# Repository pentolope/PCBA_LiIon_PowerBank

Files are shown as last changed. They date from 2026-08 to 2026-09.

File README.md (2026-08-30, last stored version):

# Single-Cell Li-Ion Power Bank

Single-cell Li-ion power bank board: USB-C input, battery charging and protection, and a regulated 5 V output capable of at least 2 A.

This repository holds the design problem for `PCBA_LiIon_PowerBank`, a single-cell Li-ion power bank board. The brief fixes the functional envelope: a USB-C input, battery charging, battery protection, a regulated 5 V output capable of at least 2 A, fuel/status indication, and a pushbutton-controlled output enable. It also states two process constraints — choose an integrated charger/power-path/boost solution where practical, and respect the layout guidance of the selected power ICs while minimizing high-current loop area — and instructs that stated requirements be treated as authoritative. Everything else is open: the brief names no part, vendor, IC, connector, cell, capacity, dimension, charge current, input power level, output-stage topology, stackup, or protection topology, so the architecture and every component choice belong to the design agent. At brief detail 2/5, the correct response is to make and document those decisions from cited evidence rather than to treat any of them as pre-fixed.

> **This board has not been designed.** There is no schematic, no layout and no
> part selection here — only the brief, a reading of the brief, and the
> scaffolding a design run needs. That is the intended state of this repository,
> not a gap in it.

## What the brief fixes, and what it leaves open

The brief pins down 13 requirements and deliberately leaves
19 decisions to whoever designs the board. The `Source` column says
which is which: `brief` is quoted from [BRIEF.md](BRIEF.md), `metadata` comes
from the benchmark catalogue, and `open` means the brief does not fix it.

| Aspect | Value | Source |
|---|---|---|
| Board function | Single-cell Li-ion power bank board | brief |
| Input interface | USB-C input | brief |
| Charging | Battery charging on the board | brief |
| Battery protection | Battery protection required (location and topology unstated) | brief |
| Output rail | Regulated 5 V, capable of at least 2 A | brief |
| Indication | Fuel/status indication (form not specified) | brief |
| User control | Pushbutton-controlled output enable | brief |
| Power IC integration preference | Integrated charger/power-path/boost solution where practical (a preference, with "practical" left undefined) | brief |
| Layout constraint | Follow the selected power ICs' layout guidance; minimize high-current loop area | brief |
| Requirement authority | Stated requirements are authoritative; where the brief is open, the agent makes and documents the decision | brief |
| Toolkit relationship | Repo consumes the shared PCBA_AutoDesignAndTest toolkit; no board-specific logic added to the toolkit | brief |
| Likely layer count | 2 or 4 (stated as "likely" in both the brief header and metadata; fixed by neither) | metadata |
| Category / difficulty / brief detail | power-management; difficulty 2; detail 2 | metadata |
| Primary stressors | charger layout, power-path routing, battery safety, USB-C power | metadata |
| Parts, connectors, cell, mechanics, charge current, input power level, output-stage and protection topology | Not fixed by the brief — design agent's choice | open |

The full split, with the verbatim brief text substantiating every fixed
requirement, is in [board/requirements.md](board/requirements.md) and
machine-readably in [board/requirements.json](board/requirements.json).

**Missing details are design freedom, not permission to fabricate unstated user
requirements.** A choice the brief left open is recorded as a decision, with its
reasoning — never promoted into a requirement.

## Benchmark position

| | |
|---|---|
| Benchmark id | 7 of 32 |
| Category | power-management |
| Difficulty | 2 / 5 |
| Brief detail | 2 / 5 |
| Likely layer count | 2 or 4 |
| Primary stressors | charger layout, power-path routing, battery safety, USB-C power |

This is a difficulty-2, detail-2 power-management board whose stressors are charger layout, power-path routing, battery safety, and USB-C power. It tests whether an agent can turn a short functional brief into a defensible power chain — sizing, selecting, and laying out a charger, a power path, and a 5 V output stage — and whether it can substantiate a 2 A output claim with real datasheet, magnetics, and thermal evidence instead of asserting it. Because the brief names no parts and no mechanics, it equally tests whether the agent keeps its own choices visible as choices rather than smuggling them in as requirements.

This repository is one of thirty-two. The suite, the protocol and the results
live in [PCBA_AutoDesignAndTest_Bench](https://github.com/pentolope/PCBA_AutoDesignAndTest_Bench).

## Repository layout

| Path | Contents |
|---|---|
| `BRIEF.md` | the supplied brief — authoritative, preserved byte for byte, never edited |
| `board/requirements.md` | what the brief fixes, what it leaves open, and where decisions get recorded |
| `board/requirements.json` | the same split, machine-readable, each fixed requirement bound to brief text |
| `board/manifest.template.json` | the toolkit's minimum manifest, pre-filled for this board |
| `board/toolchain.json` | where this board's build finds KiCad and the router |
| `benchmark/metadata.json` | the supplied catalogue entry — category, difficulty, detail, stressors |
| `docs/architecture.md` | the decisions this board must make, as questions, unanswered |
| `docs/sources.md` | the classes of evidence the design will have to cite |
| `docs/status.md` | what exists, what does not, and what is deliberately absent |
| `candidates/` | disposable search output, ignored by Git |
| `.claude/skills/` | the accountability-review skill [CLAUDE.md](CLAUDE.md) requires before a push |
| `tooling/PCBA_AutoDesignAndTest` | the shared verification/routing/release toolkit, as a pinned submodule |

## Getting the repository

The toolkit is a submodule and carries KiCad Routing Tools as a submodule of its
own, so clone recursively:

```bash
git clone --recursive https://github.com/pentolope/PCBA_LiIon_PowerBank.git
```

```bash
git submodule update --init --recursive
```

## Designing the board

Generic verification, routing and release logic is **not** written here. It is
consumed from `tooling/PCBA_AutoDesignAndTest`, which is board-agnostic by
construction and must stay that way; this repository owns the board and nothing
else. Start from
[the toolkit's onboarding guide](tooling/PCBA_AutoDesignAndTest/examples/onboarding.md),
and see [CLAUDE.md](CLAUDE.md) for the rules a design run works under.

```bash
python3 tooling/PCBA_AutoDesignAndTest/run.py preflight
```

## Brief integrity

`BRIEF.md` SHA-256 `a83c2729b4cd3572342d1c0d042245c18bb77970d150b0bb1acddd78cdec8627`

Every quotation in `board/requirements.json` is bound to those exact bytes. If
the brief ever changes, the bindings are stale by construction — which is the
point of recording the digest.

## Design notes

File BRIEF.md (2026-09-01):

# PCBA_LiIon_PowerBank — Single-Cell Li-Ion Power Bank
## Design brief

Design a single-cell Li-ion power bank board with USB-C input, battery charging, battery protection, and regulated 5 V output capable of at least 2 A. Include fuel/status indication and a pushbutton-controlled output enable. Choose an integrated charger/power-path/boost solution where practical. Respect the layout guidance of the selected power ICs and minimize high-current loop area.

## Functional requirements

- At least 2 A continuous at 5 V across the full usable cell voltage range, not only near full charge.
- Output off at cell attach and after any protection event; only a pushbutton press enables it.
- Indication separates charge state, charging, charge complete and fault, readable with no source attached.

## Power and rails

- Input operates over the Type-C vSafe5V range and draws no more than the source advertises.
- Battery rail spans the cell's discharge cut-off to its maximum charge voltage; parts on it are rated above that maximum.
- Cell-side current at rated output and minimum cell voltage, not output current, sizes conductors, switches and magnetics and sets over-current margin.
- Standby current from the cell, output off and no source attached, stays small against the cell's self-discharge.

## Charging and battery protection

- Charging is current- and voltage-limited to the cell's ratings, terminates, and respects the source's current limit.
- Over-voltage, under-voltage, over-current and short-circuit protection hold with any programmable device unpowered or unprogrammed.
- Shorted output, reversed cell, or source removed mid-charge leaves the board undamaged and protection intact.

## Interfaces, indication and control

- USB-C input presents the sink CC terminations Type-C requires, works in either orientation, ESD-protected at the connector.
- Pushbutton input debounced, press and hold behaviour defined, with no floating node and no standing idle current.

## Layout, thermal and mechanical

- Switching and high-current loops closed over minimum area, capacitors returned to their IC's power ground over unbroken copper, sense nodes Kelvin-connected clear of switching nodes.
- Conductor and via cross-sections meet a stated temperature-rise limit at worst-case cell-side current.
- Rated output sustained in still air at room ambient: no part over rating, no thermal foldback, cell within its permitted temperature range.
- Connector, button and indicators on one face and mechanical reference; keepouts defined for the cell and its connection.

## Test and bring-up

- Test points at VBUS, cell terminals, output and ground, with Kelvin pairs for efficiency measurement.
- The board runs from a bench supply in place of the cell and comes up safely with no cell fitted.

## Open choices

- Charger, power-path, boost and protection partitioning: one integrated device or discrete stages.
- Whether the input negotiates above vSafe5V (Type-C advertisement, BC1.2, USB PD), and the charge rate that follows.
- Whether output works while a source is attached, and what charging does then; the behaviour must be deterministic.
- Indicator type and charge-state resolution; output connector family; cell attachment; temperature-qualified charging.

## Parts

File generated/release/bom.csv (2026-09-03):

Quantity | Designator | Comment | Footprint | LCSC Part #
7 | C1,C2,C3,C6,C14,C16,C17 | 100nF | Capacitor_SMD:C_0603_1608Metric | C14663
7 | C4,C7,C8,C10,C11,C12,C13 | 22uF | Capacitor_SMD:C_1206_3216Metric | C380359
2 | C5,C9 | 10uF | Capacitor_SMD:C_0805_2012Metric | C15850
1 | C15 | 2.2uF | Capacitor_SMD:C_0603_1608Metric | C23630
4 | D1,D2,D3,D4 | KT-0603G | LED_SMD:LED_0603_1608Metric | C12624
1 | D5 | KT-0603R | LED_SMD:LED_0603_1608Metric | C2286
6 | D6,D7,D8,D9,D10,D11 | TPD1E10B06DPYR | LiIonPowerBank:TI_X1SON-2_1.0x0.6mm_P0.65mm | C48260
2 | J1,J2 | TYPE-C-31-M-12 | Connector_USB:USB_C_Receptacle_HRO_TYPE-C-31-M-12 | C165948
1 | J3 | B2P-VH(LF)(SN) | Connector_JST:JST_VH_B2P-VH_1x02_P3.96mm_Vertical | C160315
1 | L1 | 1uH | LiIonPowerBank:L_Sunlord_SWPA8040S | C96968
2 | Q1,Q6 | AO3415A | Package_TO_SOT_SMD:SOT-23 | C133233
2 | Q2,Q7 | AO3400A | Package_TO_SOT_SMD:SOT-23 | C20917
3 | Q3,Q4,Q5 | AO8810 | Package_SO:TSSOP-8_3x3mm_P0.65mm | C21426
1 | Q8 | AO3401A | Package_TO_SOT_SMD:SOT-23 | C15127
2 | R1,R2 | 5.1k | Resistor_SMD:R_0603_1608Metric | C23186
2 | R3,R10 | 2.2R | Resistor_SMD:R_0603_1608Metric | C25226
1 | R4 | 4.7k | Resistor_SMD:R_0603_1608Metric | C23162
3 | R5,R7,R15 | 100k | Resistor_SMD:R_0603_1608Metric | C25803
6 | R6,R11,R13,R16,R20,R21 | 10k | Resistor_SMD:R_0603_1608Metric | C25804
1 | R8 | 470k | Resistor_SMD:R_0603_1608Metric | C23178
1 | R9 | 1.5k | Resistor_SMD:R_0603_1608Metric | C22843
3 | R12,R14,R17 | 1M | Resistor_SMD:R_0603_1608Metric | C22935
1 | R18 | 100R | Resistor_SMD:R_0603_1608Metric | C22775
1 | R19 | 1k | Resistor_SMD:R_0603_1608Metric | C21190
1 | SW1 | TS-1187A-B-A-B | LiIonPowerBank:SW_TS-1187A_5.1x5.1mm | C318884
1 | U1 | IP5306 | LiIonPowerBank:ESOP-8_3.9x4.9mm_P1.27mm_EP2.09x2.09mm | C181692
1 | U2 | DW01A | Package_TO_SOT_SMD:SOT-23-6 | C351410
1 | U3 | LM393 | Package_SO:SOIC-8_3.9x4.9mm_P1.27mm | C7955
1 | U4 | TLV431A | Package_TO_SOT_SMD:SOT-23 | C56765

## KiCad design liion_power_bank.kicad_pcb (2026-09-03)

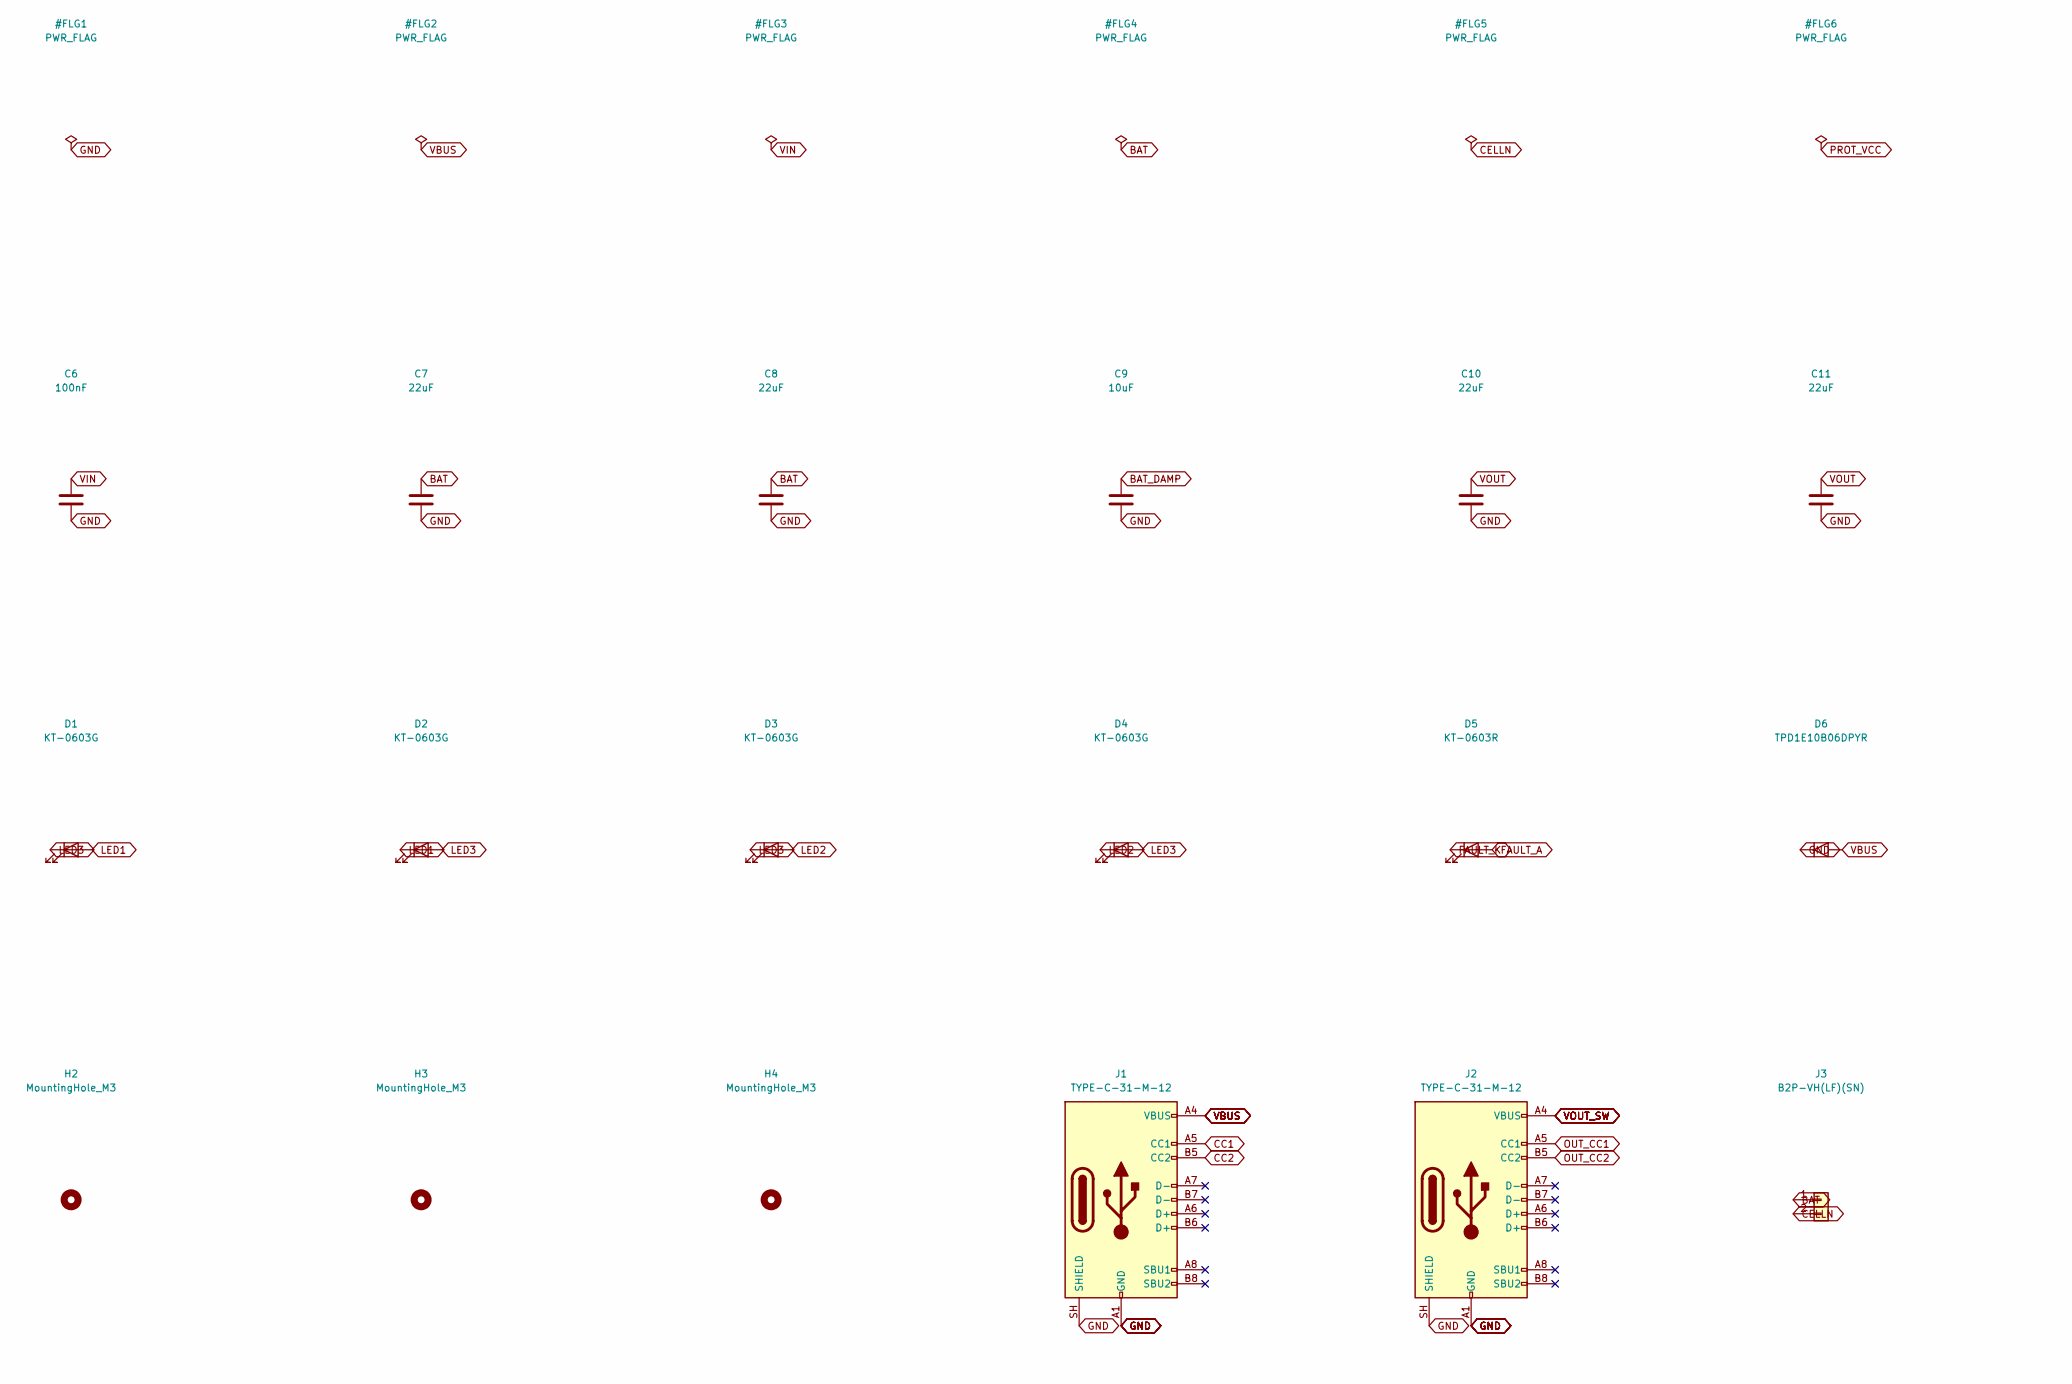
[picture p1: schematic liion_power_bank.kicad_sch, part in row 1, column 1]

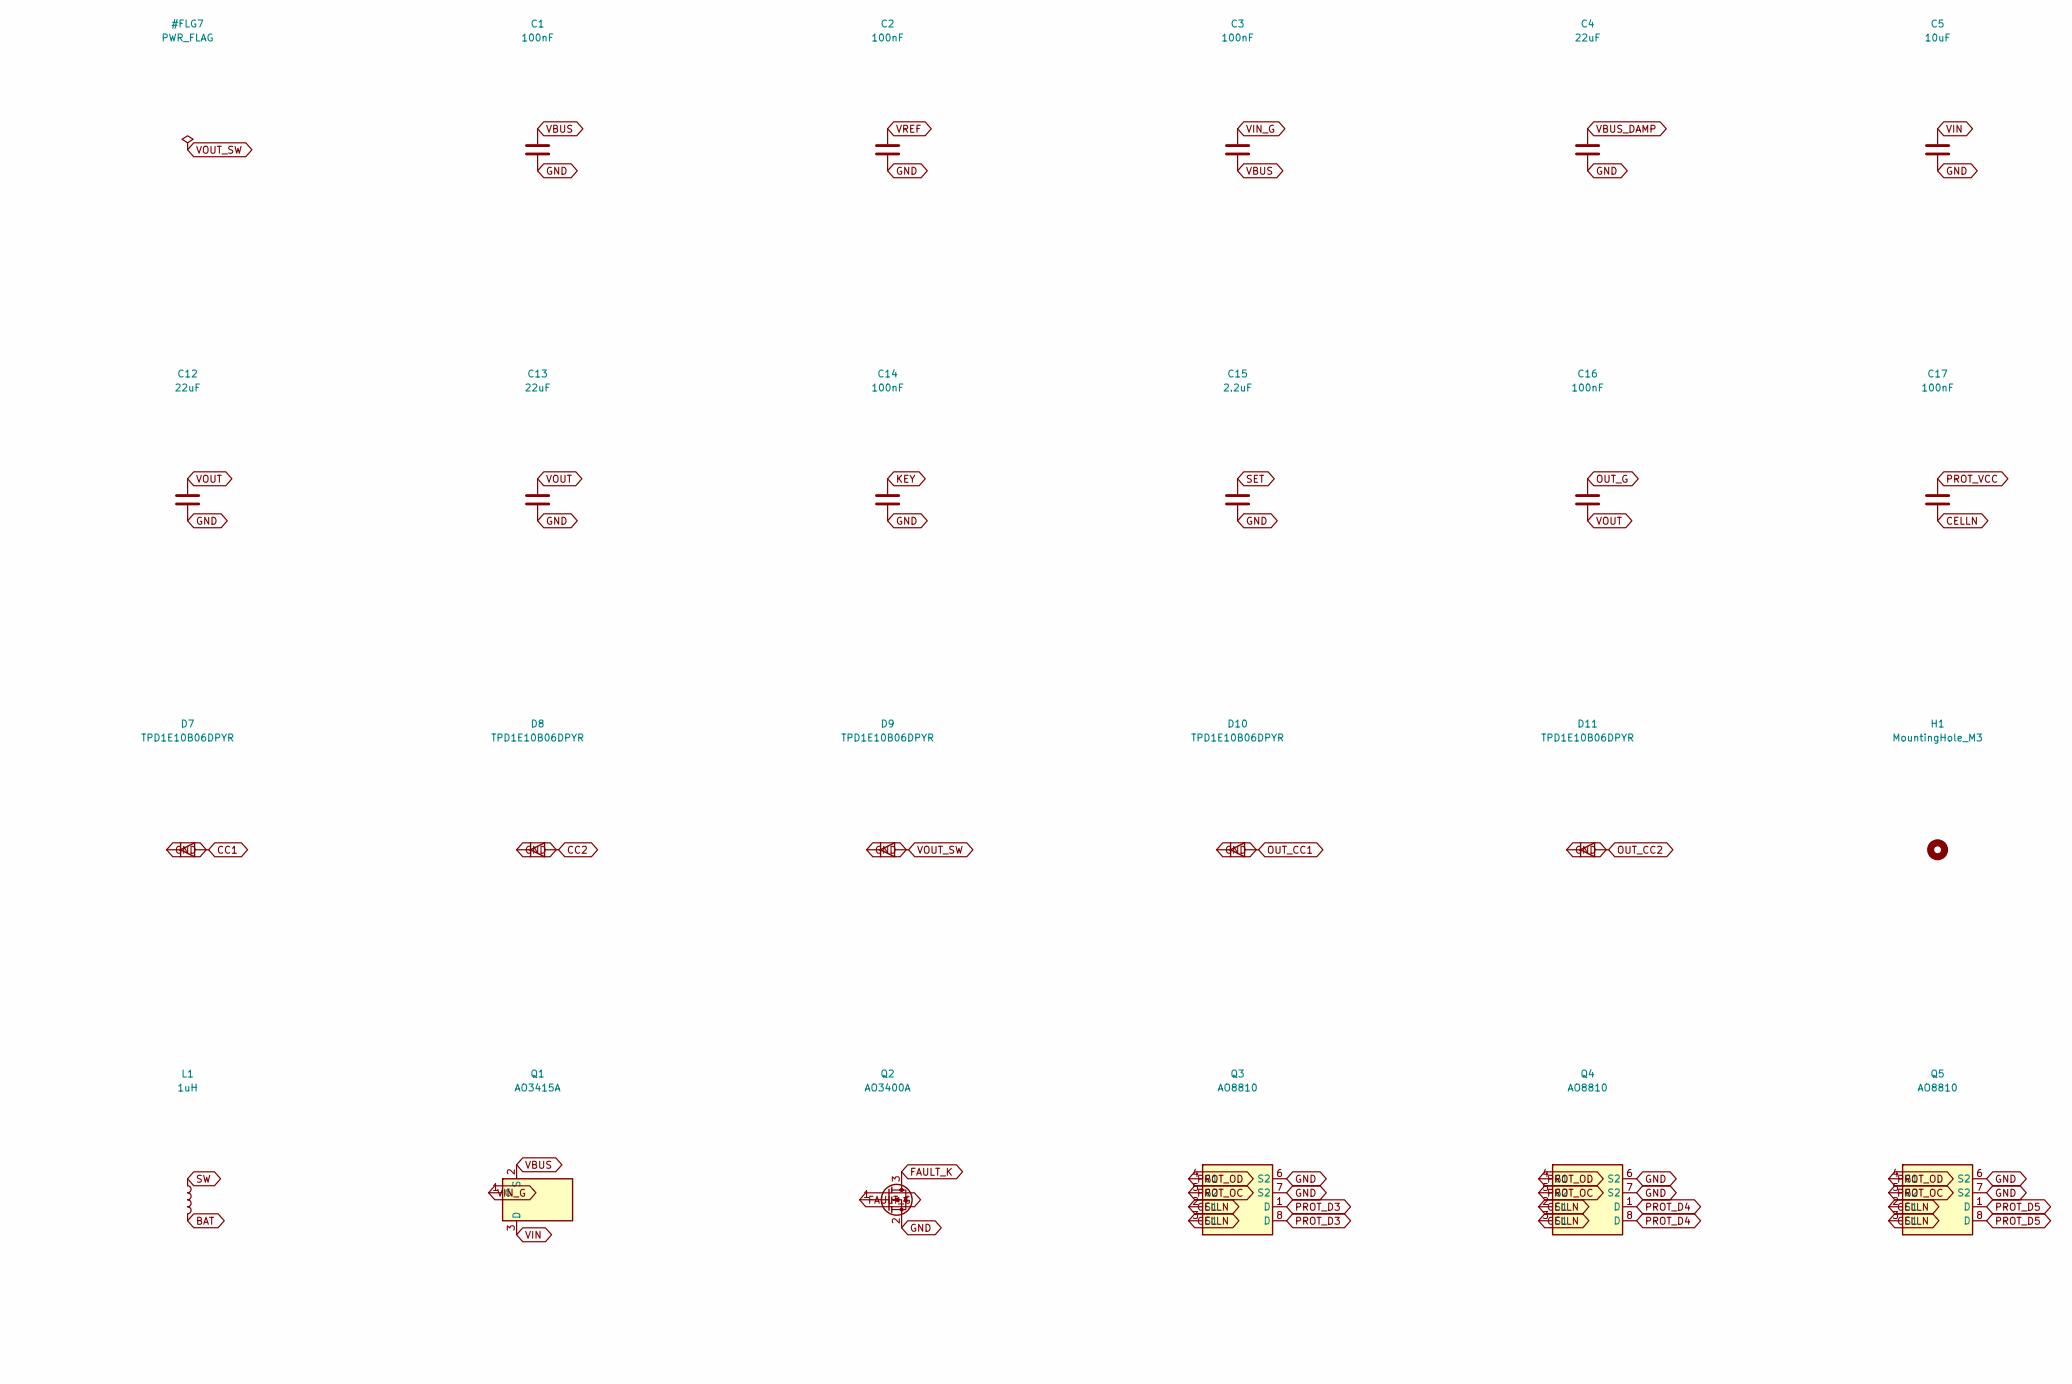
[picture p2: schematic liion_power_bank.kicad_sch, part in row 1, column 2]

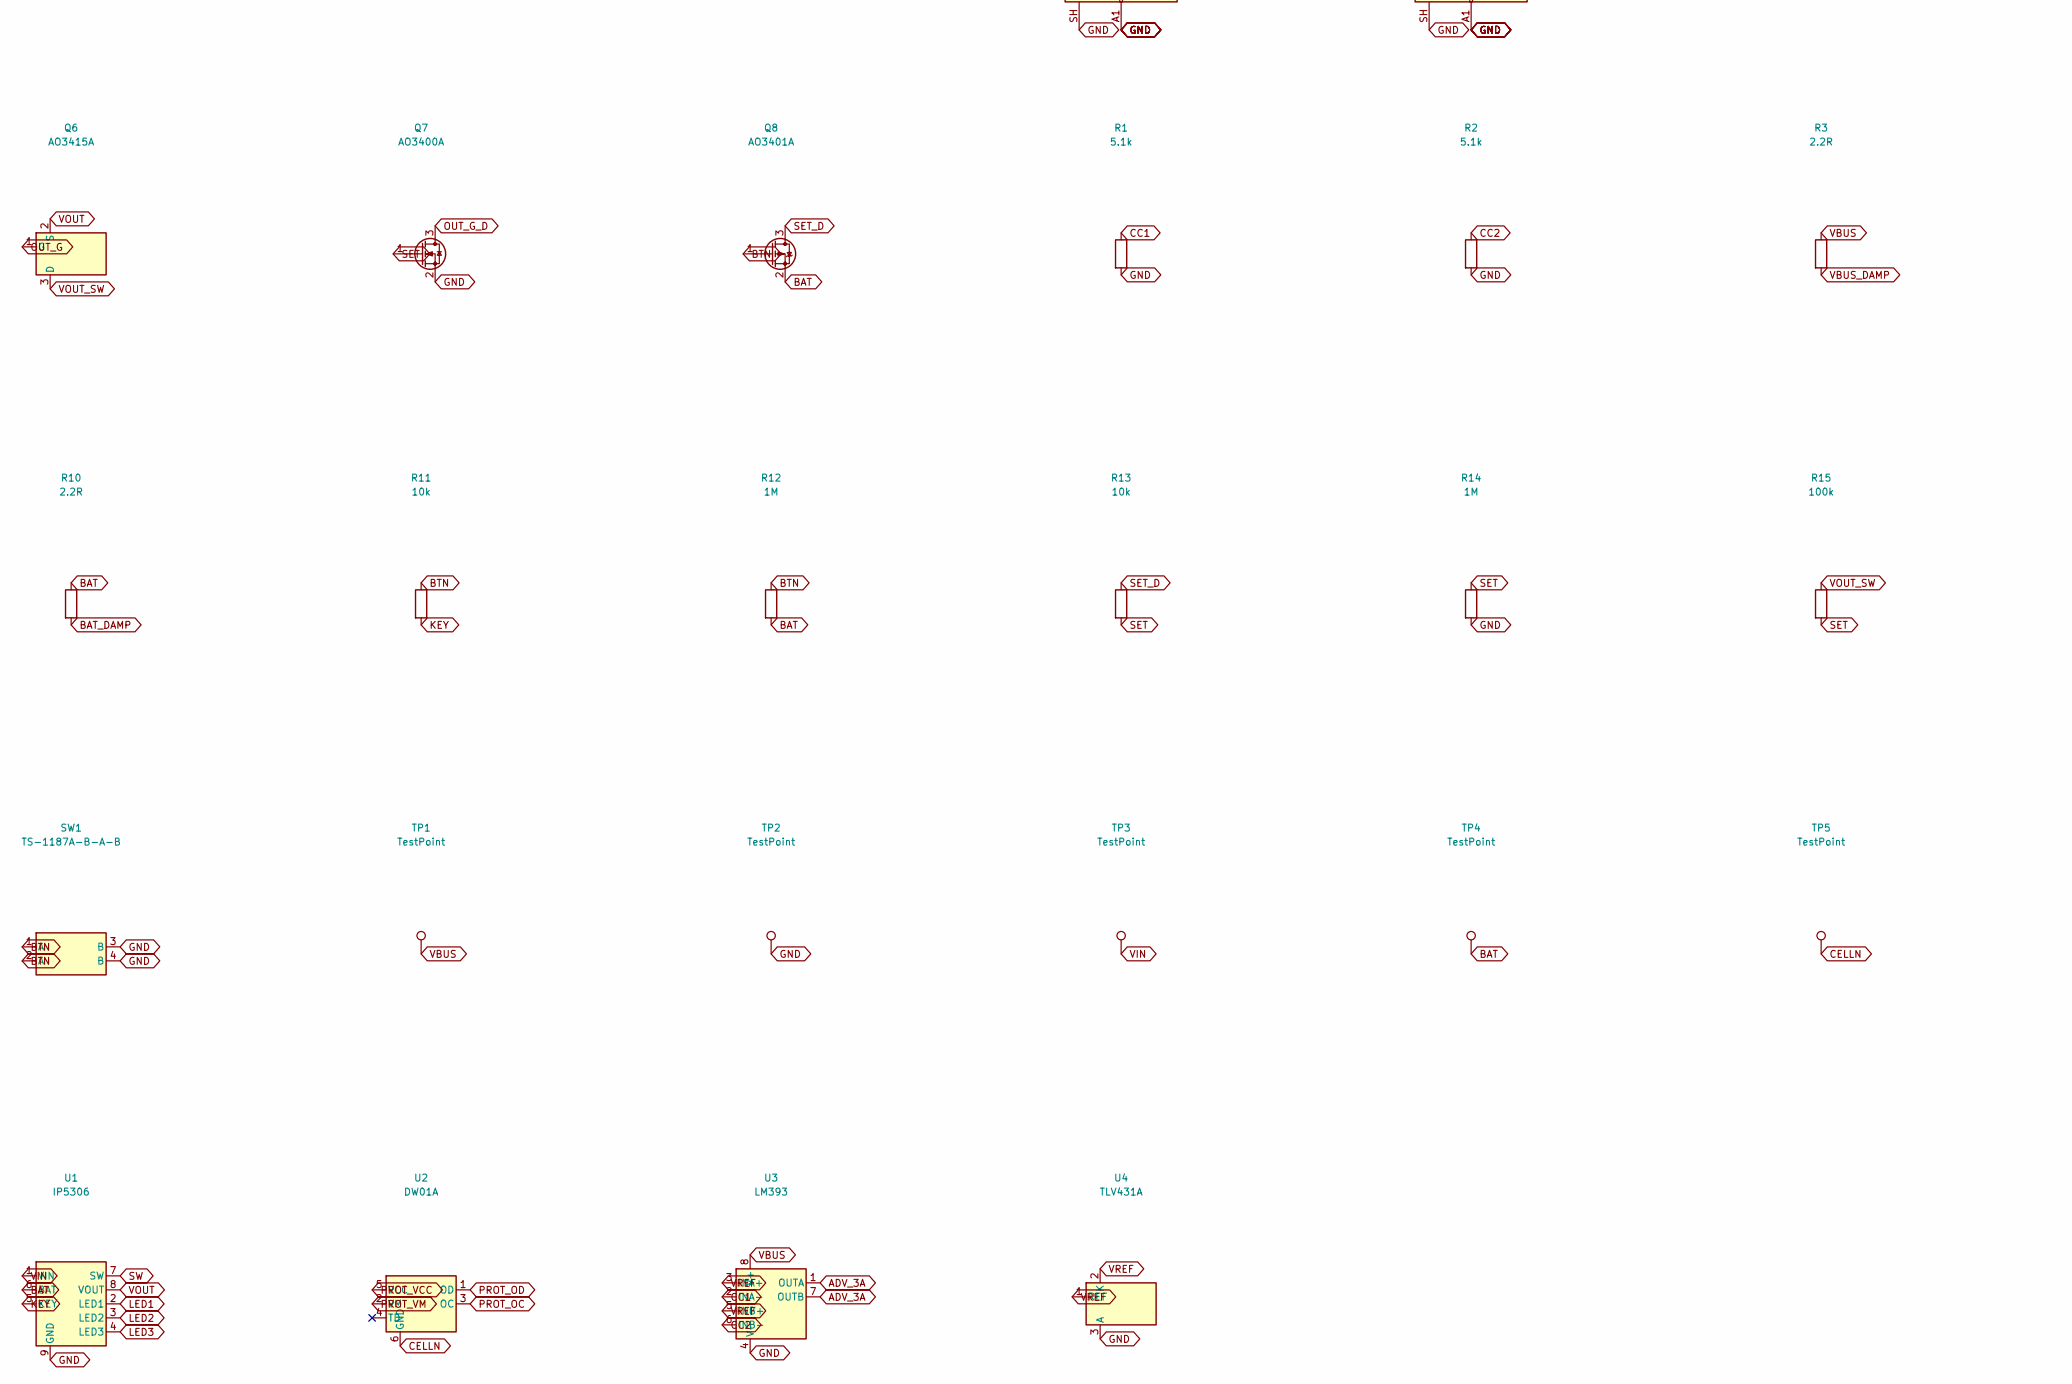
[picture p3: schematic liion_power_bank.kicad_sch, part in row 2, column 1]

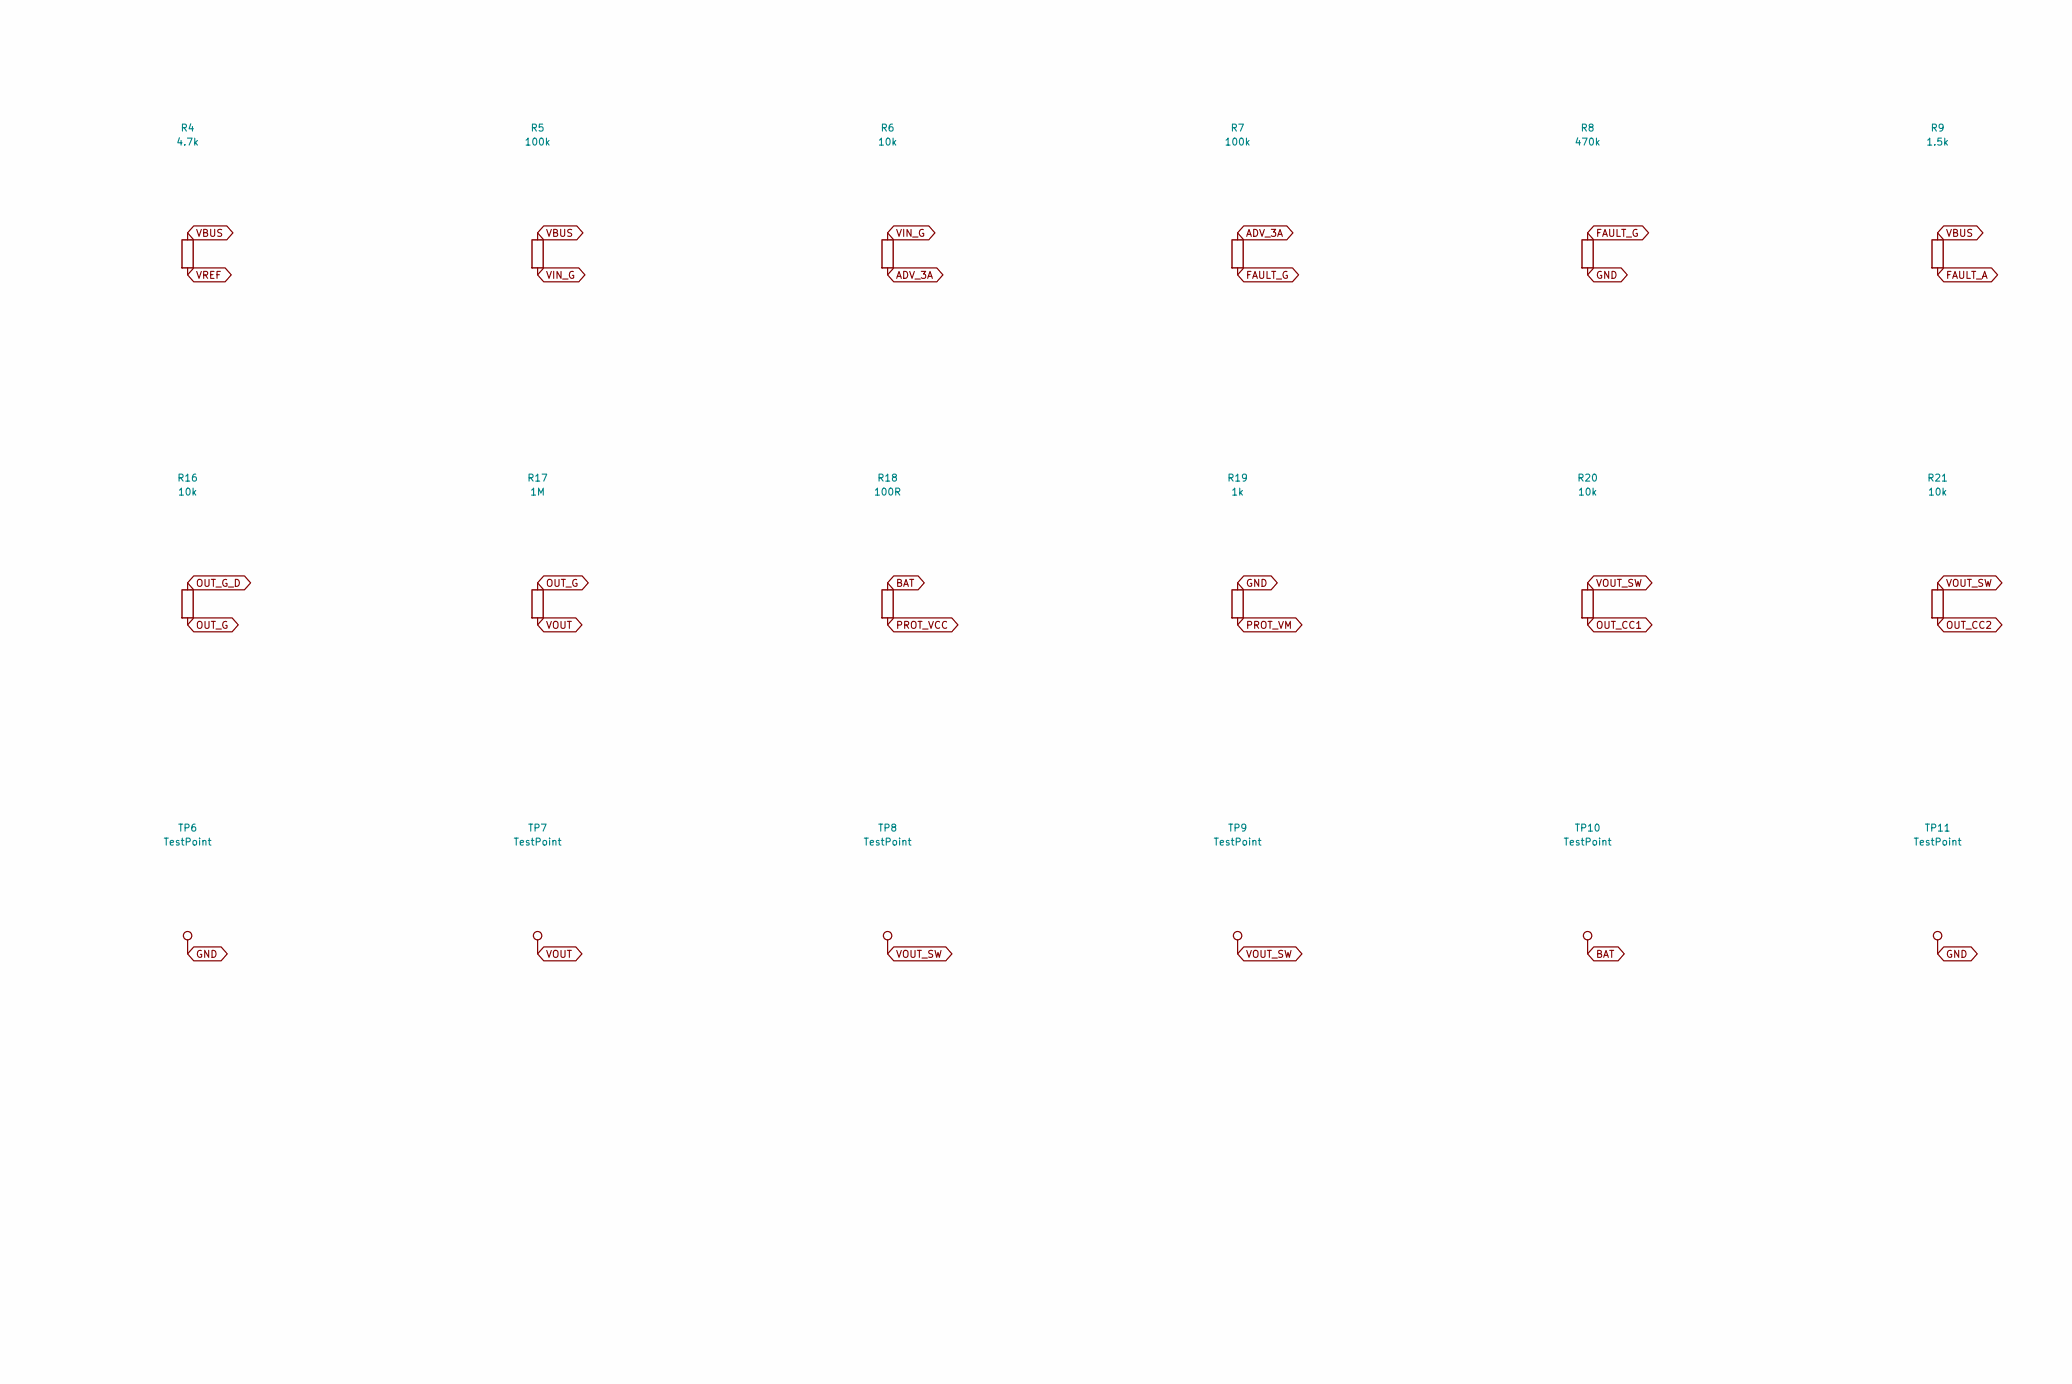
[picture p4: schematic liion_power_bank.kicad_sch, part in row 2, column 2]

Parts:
C1, C2, C3, C6, C14, C16, C17: 100nF; C_0603_1608Metric; MPN CC0603KRX7R9BB104; LCSC C14663
C4, C7, C8, C10, C11, C12, C13: 22uF; C_1206_3216Metric; MPN TCC1206X5R226M250HT; LCSC C380359
C5, C9: 10uF; C_0805_2012Metric; MPN CL21A106KAYNNNE; LCSC C15850
C15: 2.2uF; C_0603_1608Metric; MPN CL10A225KO8NNNC; LCSC C23630
D1, D2, D3, D4: KT-0603G; LED_0603_1608Metric; MPN KT-0603G; LCSC C12624
D5: KT-0603R; LED_0603_1608Metric; MPN KT-0603R; LCSC C2286
D6, D7, D8, D9, D10, D11: TPD1E10B06DPYR; TI_X1SON-2_1.0x0.6mm_P0.65mm; MPN TPD1E10B06DPYR; LCSC C48260
H1, H2, H3, H4: MountingHole_M3; MountingHole_3.2mm_M3
J1, J2: TYPE-C-31-M-12; USB_C_Receptacle_HRO_TYPE-C-31-M-12; MPN TYPE-C-31-M-12; LCSC C165948
J3: B2P-VH(LF)(SN); JST_VH_B2P-VH_1x02_P3.96mm_Vertical; MPN B2P-VH(LF)(SN); LCSC C160315
L1: 1uH; L_Sunlord_SWPA8040S; MPN SWPA8040S1R0NT; LCSC C96968
Q1, Q6: AO3415A; SOT-23; MPN AO3415A; LCSC C133233
Q2, Q7: AO3400A; SOT-23; MPN AO3400A; LCSC C20917
Q3, Q4, Q5: AO8810; TSSOP-8_3x3mm_P0.65mm; MPN AO8810; LCSC C21426
Q8: AO3401A; SOT-23; MPN AO3401A; LCSC C15127
R1, R2: 5.1k; R_0603_1608Metric; MPN 0603WAF5101T5E; LCSC C23186
R3, R10: 2.2R; R_0603_1608Metric; MPN 0603WAJ022JT5E; LCSC C25226
R4: 4.7k; R_0603_1608Metric; MPN 0603WAF4701T5E; LCSC C23162
R5, R7, R15: 100k; R_0603_1608Metric; MPN 0603WAF1003T5E; LCSC C25803
R6, R11, R13, R16, R20, R21: 10k; R_0603_1608Metric; MPN 0603WAF1002T5E; LCSC C25804
R8: 470k; R_0603_1608Metric; MPN 0603WAF4703T5E; LCSC C23178
R9: 1.5k; R_0603_1608Metric; MPN 0603WAF1501T5E; LCSC C22843
R12, R14, R17: 1M; R_0603_1608Metric; MPN 0603WAF1004T5E; LCSC C22935
R18: 100R; R_0603_1608Metric; MPN 0603WAF1000T5E; LCSC C22775
R19: 1k; R_0603_1608Metric; MPN 0603WAF1001T5E; LCSC C21190
SW1: TS-1187A-B-A-B; SW_TS-1187A_5.1x5.1mm; MPN TS-1187A-B-A-B; LCSC C318884
TP1, TP2, TP3, TP4, TP5, TP6, TP7, TP8, TP9, TP10, TP11: TestPoint; TestPoint_Pad_D1.0mm
U1: IP5306; ESOP-8_3.9x4.9mm_P1.27mm_EP2.09x2.09mm; MPN IP5306; LCSC C181692
U2: DW01A; SOT-23-6; MPN DW01A; LCSC C351410
U3: LM393; SOIC-8_3.9x4.9mm_P1.27mm; MPN LM393DR2G; LCSC C7955
U4: TLV431A; SOT-23; MPN TLV431AIDBZR; LCSC C56765

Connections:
ADV_3A: R6.2, R7.1, U3.1 (OUTA), U3.7 (OUTB)
BAT: C7.1, C8.1, J3.1, L1.2, Q8.2 (S), R10.1, R12.2, R18.1, TP4.1, TP10.1, U1.6 (BAT)
BAT_DAMP: C9.1, R10.2
BTN: Q8.1 (G), R11.1, R12.1, SW1.1 (A), SW1.2 (A)
CC1: D7.2 (A), J1.A5 (CC1), R1.1, U3.2 (INA-)
CC2: D8.2 (A), J1.B5 (CC2), R2.1, U3.6 (INB-)
CELLN: C17.2, J3.2, Q3.2 (S1), Q3.3 (S1), Q4.2 (S1), Q4.3 (S1), Q5.2 (S1), Q5.3 (S1), TP5.1, U2.6 (GND)
FAULT_A: D5.2 (A), R9.2
FAULT_G: Q2.1 (G), R7.2, R8.1
FAULT_K: D5.1 (K), Q2.3 (D)
GND: C1.2, C2.2, C4.2, C5.2, C6.2, C7.2, C8.2, C9.2, C10.2, C11.2, C12.2, C13.2, C14.2, C15.2, D6.1 (K), D7.1 (K), D8.1 (K), D9.1 (K), D10.1 (K), D11.1 (K), J1.A1 (GND), J1.A12 (GND), J1.B1 (GND), J1.B12 (GND), J1.SH (SHIELD), J2.A1 (GND), J2.A12 (GND), J2.B1 (GND), J2.B12 (GND), J2.SH (SHIELD), Q2.2 (S), Q3.6 (S2), Q3.7 (S2), Q4.6 (S2), Q4.7 (S2), Q5.6 (S2), Q5.7 (S2), Q7.2 (S), R1.2, R2.2, R8.2, R14.2, R19.1, SW1.3 (B), SW1.4 (B), TP2.1, TP6.1, TP11.1, U1.9 (GND), U3.4 (V-), U4.3 (A)
KEY: C14.1, R11.2, U1.5 (KEY)
LED1: D1.2 (A), D2.1 (K), U1.2 (LED1)
LED2: D3.2 (A), D4.1 (K), U1.3 (LED2)
LED3: D1.1 (K), D2.2 (A), D3.1 (K), D4.2 (A), U1.4 (LED3)
OUT_CC1: D10.2 (A), J2.A5 (CC1), R20.2
OUT_CC2: D11.2 (A), J2.B5 (CC2), R21.2
OUT_G: C16.1, Q6.1 (G), R16.2, R17.1
OUT_G_D: Q7.3 (D), R16.1
PROT_D3: Q3.1 (D), Q3.8 (D)
PROT_D4: Q4.1 (D), Q4.8 (D)
PROT_D5: Q5.1 (D), Q5.8 (D)
PROT_OC: Q3.5 (G2), Q4.5 (G2), Q5.5 (G2), U2.3 (OC)
PROT_OD: Q3.4 (G1), Q4.4 (G1), Q5.4 (G1), U2.1 (OD)
PROT_VCC: C17.1, R18.2, U2.5 (VCC)
PROT_VM: R19.2, U2.2 (VM)
SET: C15.1, Q7.1 (G), R13.2, R14.1, R15.2
SET_D: Q8.3 (D), R13.1
SW: L1.1, U1.7 (SW)
VBUS: C1.1, C3.2, D6.2 (A), J1.A4 (VBUS), J1.A9 (VBUS), J1.B4 (VBUS), J1.B9 (VBUS), Q1.2 (S), R3.1, R4.1, R5.1, R9.1, TP1.1, U3.8 (V+)
VBUS_DAMP: C4.1, R3.2
VIN: C5.1, C6.1, Q1.3 (D), TP3.1, U1.1 (VIN)
VIN_G: C3.1, Q1.1 (G), R5.2, R6.1
VOUT: C10.1, C11.1, C12.1, C13.1, C16.2, Q6.2 (S), R17.2, TP7.1, U1.8 (VOUT)
VOUT_SW: D9.2 (A), J2.A4 (VBUS), J2.A9 (VBUS), J2.B4 (VBUS), J2.B9 (VBUS), Q6.3 (D), R15.1, R20.1, R21.1, TP8.1, TP9.1
VREF: C2.1, R4.2, U3.3 (INA+), U3.5 (INB+), U4.1 (REF), U4.2 (K)

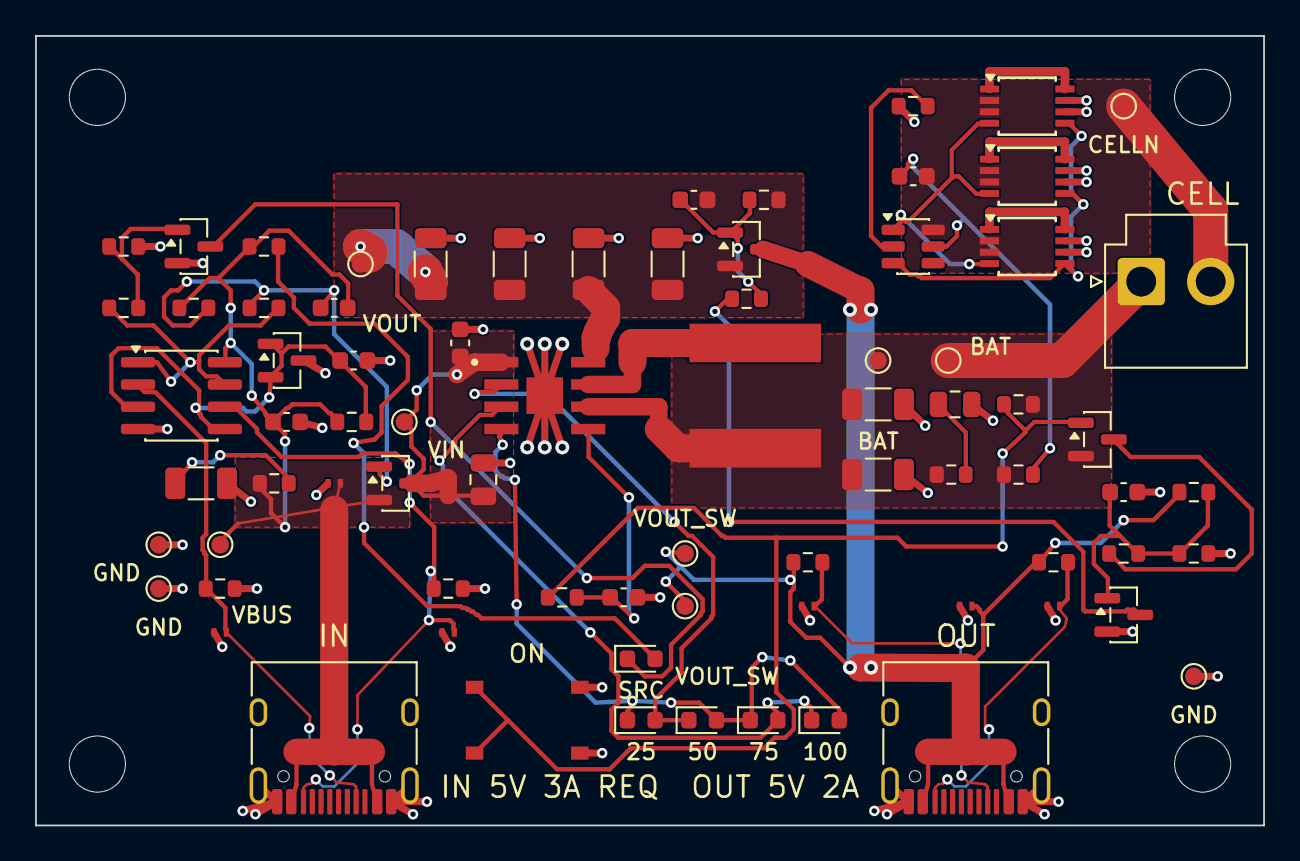
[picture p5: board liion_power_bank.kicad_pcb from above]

Board: 2 copper layers, 70.0 x 45.0 mm, 81 parts (0 on the bottom side), 36 nets.

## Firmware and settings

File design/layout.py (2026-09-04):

"""The board: outline, placement, pours and silkscreen, from the design
source.

Board coordinates run x right and y UP from the lower-left corner, which is
the frame every dimension in this module is stated in. KiCad's own y runs
down, so the mapping is applied once, here.

The arrangement follows the current. Both receptacles sit on the bottom edge
because that is the face the brief puts the user's connections on, and the
button and the indicators sit in the band immediately above them, on the same
face. The cell connector is on the opposite edge, behind a keepout the cell
and its leads occupy, so nothing the user touches is near the cell.

Between the two runs the power chain, left to right: the receptacle, the
damper, the switch the advertisement gates, the converter, and the enable
switch that feeds the output receptacle. The converter's own loop - its
switch pin, the inductor, the cell rail capacitance and its ground pad - is
the one structure placed for area rather than for order, because it is the
only loop on the board whose geometry is a requirement.
"""
from __future__ import annotations

import json
import math
import os
import sys

from . import ksym, netlist

_TOOLKIT = os.path.join(
    os.path.dirname(os.path.dirname(os.path.abspath(__file__))),
    "tooling", "PCBA_AutoDesignAndTest")
if _TOOLKIT not in sys.path:
    sys.path.insert(0, _TOOLKIT)

from pcbqa import board as pcbqa_board  # noqa: E402
from pcbqa import headless  # noqa: E402

headless.suppress_blocking_ui()

import pcbnew  # noqa: E402

REPO_ROOT = os.path.dirname(os.path.dirname(os.path.abspath(__file__)))
BOARD_PATH = os.path.join(REPO_ROOT, netlist.PROJECT_NAME + ".kicad_pcb")
PLACEMENT_PATH = os.path.join(REPO_ROOT, "constraints", "placement.json")

FOOTPRINT_SEARCH_PATHS = (
    os.path.join(REPO_ROOT, "library"),
    "/usr/share/kicad/footprints",
)

ORIGIN_MM = (30.0, 90.0)

BOARD_W_MM = 70.0
BOARD_H_MM = 45.0

#: The receptacles' mating faces stand on the board edge, so their courtyards
#: reach exactly to y = 0 and a plug meets the board where the board ends.
RECEPTACLE_FACE_OFFSET_MM = 5.4
INPUT_RECEPTACLE_X_MM = 17.0
OUTPUT_RECEPTACLE_X_MM = 53.0

#: The region the cell and its leads occupy. Nothing is placed inside it and
#: the silkscreen marks it, because the cell is the one part of this assembly
#: the board does not carry.
CELL_KEEPOUT_MM = (61.0, 25.0, 69.5, 37.0)

EDGE_WIDTH_MM = 0.1
TRACK_WIDTH_MM = 0.25
#: Width of the generated copper that carries cell-side current. Wider than
#: the requirement asks for, because these are the conductors that carry the
#: whole cell current and there is room for them.
POWER_TRACK_WIDTH_MM = 2.0
CLEARANCE_MM = 0.15
EDGE_CLEARANCE_MM = 0.3
VIA_DIAMETER_MM = 0.6
VIA_DRILL_MM = 0.3
POWER_VIA_DIAMETER_MM = 0.8
POWER_VIA_DRILL_MM = 0.4
ZONE_INSET_MM = 0.5
#: The shortest piece of copper the board accepts away from a pad or a via.
#: A fragment below this is what a search leaves where it turns a corner,
#: not a route, and the board is judged against it as well as routed to it.
MIN_SEGMENT_MM = 0.1

#: How far a via's annulus is kept from any pad's solder-mask opening. A via
#: that touches an opening cannot be tented or plugged, and one that reaches
#: an opening a paste aperture feeds wicks the joint's solder into its
#: barrel. The board is drawn with no mask expansion, so an opening is the
#: pad's own outline and this is a distance the placement can search against.
VIA_MASK_CLEARANCE_MM = 0.15

STITCH_TRACK_WIDTH_MM = 0.4
STITCH_GAP_MM = 0.35

MOUNTING_HOLES_MM = {
    "H1": (3.5, 3.5),
    "H2": (66.5, 3.5),
    "H3": (3.5, 41.5),
    "H4": (66.5, 41.5),
}

#: The band the cell's own conductors run in, and the region the cell body
#: occupies. Nothing is placed inside it.


#: Parts a placement search may not move, and why.
#:
#: The receptacles, the cell connector, the button, the indicators and the
#: fasteners are the board's mechanical contract with the person holding it.
#: The test points are its service contract. The inductor, the converter and
#: the cell-rail capacitance are the switching loop, whose area is a
#: requirement rather than a result.
LOCKED_REFERENCES = tuple(sorted(
    ["J1", "J2", "J3", "SW1", "H1", "H2", "H3", "H4",
     "U1", "L1", "C7", "C8"]
    + ["D%d" % index for index in range(1, 6)]
    + ["TP%d" % index for index in range(1, 12)]))


#: Every part's pose, as (x, y, rotation) in the board frame.
#:
#: The bands the parts fall into are the bands the power nets occupy, because
#: each of those nets is poured and two pours that overlap are two nets
#: wanting the same copper. Left to right along the board: the input and what
#: reads it, the charger input, the converter, the inductor and the cell
#: rail, the cell's own protection, and the output. The one place two power
#: nets are unavoidably adjacent is at a device's own pins, and there the
#: copper is generated as a neck rather than poured.
SEED_PLACEMENT = {
    # --- the face the user meets: the two receptacles on the edge, and the
    # button and the indicators in the gap between them ------------------
    "J1": (INPUT_RECEPTACLE_X_MM, RECEPTACLE_FACE_OFFSET_MM, 180.0),
    "J2": (OUTPUT_RECEPTACLE_X_MM, RECEPTACLE_FACE_OFFSET_MM, 180.0),
    "SW1": (28.0, 6.0, 0.0),
    "D1": (34.5, 6.0, 0.0),
    "D2": (38.0, 6.0, 0.0),
    "D3": (41.5, 6.0, 0.0),
    "D4": (45.0, 6.0, 0.0),
    "D5": (34.5, 9.5, 0.0),

    # --- what the input receptacle's own conductors meet ------------------
    "D7": (10.5, 11.0, 0.0),
    "R1": (10.5, 13.5, 0.0),
    "D8": (23.5, 11.0, 0.0),
    "R2": (23.5, 13.5, 0.0),
    "TP1": (10.5, 16.0, 0.0),
    "TP2": (7.0, 16.0, 0.0),
    "TP6": (7.0, 13.5, 0.0),

    # --- the damper, the clamp and the switch the advertisement gates -----
    "C4": (9.5, 19.5, 0.0),
    "R3": (13.5, 19.5, 0.0),
    "D6": (17.0, 19.5, 0.0),
    "Q1": (20.5, 19.5, 0.0),

    # --- the detector ----------------------------------------------------
    "U3": (9.0, 24.5, 0.0),
    "C1": (14.0, 23.0, 0.0),
    "U4": (14.0, 26.5, 0.0),
    "C2": (18.0, 26.5, 0.0),
    "R4": (18.0, 23.0, 0.0),
    "R5": (9.0, 29.5, 0.0),
    "R6": (13.0, 29.5, 0.0),
    "C3": (17.0, 29.5, 0.0),
    "R7": (5.0, 29.5, 0.0),
    "R8": (5.0, 33.0, 0.0),
    "Q2": (9.0, 33.0, 0.0),
    "R9": (13.0, 33.0, 0.0),

    # --- the charger input -----------------------------------------------
    "C5": (25.5, 20.0, 90.0),
    "C6": (25.5, 27.5, 90.0),
    "TP3": (21.0, 23.0, 0.0),

    # --- the converter, its inductor and the capacitance behind each ------
    "U1": (29.0, 24.5, 0.0),
    "L1": (41.0, 24.5, 270.0),
    "C10": (22.5, 32.0, 90.0),
    "C11": (27.0, 32.0, 90.0),
    "C12": (31.5, 32.0, 90.0),
    "C13": (36.0, 32.0, 90.0),
    "C7": (48.0, 20.0, 0.0),
    "C8": (48.0, 24.0, 0.0),
    "R10": (52.0, 20.0, 0.0),
    "C9": (52.0, 24.0, 0.0),
    "TP7": (18.5, 32.0, 0.0),
    "TP10": (52.0, 26.5, 0.0),

    # --- the push button's network ----------------------------------------
    "R11": (30.0, 13.0, 0.0),
    "C14": (33.5, 13.0, 0.0),
    "R12": (56.0, 24.0, 0.0),

    # --- the cell, its connector and its protection ----------------------
    "J3": (63.0, 31.0, 0.0),
    "TP4": (48.0, 26.5, 0.0),
    "TP5": (62.0, 41.0, 0.0),
    "R18": (56.0, 20.0, 0.0),
    "U2": (50.0, 33.0, 0.0),
    "C17": (50.0, 37.0, 0.0),
    "R19": (50.0, 41.0, 0.0),
    "Q3": (56.5, 33.0, 0.0),
    "Q4": (56.5, 37.0, 0.0),
    "Q5": (56.5, 41.0, 0.0),

    # --- the output enable latch and the output receptacle ---------------
    "D9": (53.0, 12.5, 0.0),
    "D10": (44.0, 12.5, 0.0),
    "D11": (58.0, 12.5, 0.0),
    "R20": (44.0, 15.0, 0.0),
    "R21": (58.0, 15.0, 0.0),
    "Q6": (40.5, 32.0, 0.0),
    "TP8": (37.0, 12.5, 0.0),
    "TP9": (37.0, 15.5, 0.0),
    "TP11": (66.0, 8.5, 0.0),
    "Q7": (62.0, 12.0, 0.0),
    "Q8": (60.5, 22.0, 0.0),
    "R13": (62.0, 15.5, 0.0),
    "R14": (66.0, 15.5, 0.0),
    "C15": (62.0, 19.0, 0.0),
    "R15": (66.0, 19.0, 0.0),
    "R16": (40.5, 28.5, 0.0),
    "R17": (41.5, 35.5, 0.0),
    "C16": (37.5, 35.5, 0.0),
}
for _reference, (_x, _y) in MOUNTING_HOLES_MM.items():
    SEED_PLACEMENT[_reference] = (_x, _y, 0.0)


# ---------------------------------------------------------------------------
# pours

#: The ground pour on the back layer: everything except the band the cell's
#: own negative conductor occupies, which is a separate net.
GROUND_POUR_MM = (ZONE_INSET_MM, ZONE_INSET_MM,
                  BOARD_W_MM - ZONE_INSET_MM, BOARD_H_MM - ZONE_INSET_MM)

#: Nets poured on the front layer, and the margin each pour reaches beyond
#: the pads it has to join. Each is a net whose own current is large enough
#: that a track would have to be wide, and the pour is what makes it wide
#: without anybody choosing a number. The box is derived from where the pads
#: actually are, so a pour cannot describe a placement that has changed.
FRONT_POUR_NETS = {
    "VBUS": 1.0,
    "VIN": 1.0,
    "VOUT": 1.0,
    "BAT": 1.0,
    "CELLN": 1.0,
}

#: Pads a pour must reach but must not be sized around, because they sit far
#: from the rest of the net and the pour would have to cross the board to
#: contain them. Each is instead reached by the router or by generated
#: copper, and the reason is stated with it.
POUR_EXCLUDED_PADS = {
    # the input receptacle's own supply pads, which the escape reaches
    "VBUS": ("J1.A4", "J1.A9", "J1.B4", "J1.B9", "TP1.1", "R9.1",
             "U3.8", "C1.1", "R4.1", "R5.1", "C3.2"),
    # the converter's own pins: four power nets on 1.27 mm centres, which no
    # arrangement of rectangles can hold apart. Generated necks carry them
    # out of the package and the pours pick them up there.
    "VIN": ("U1.1", "TP3.1", "Q1.3"),
    "VOUT": ("U1.8",),
    "BAT": ("U1.6", "J3.1"),
    "CELLN": ("J3.2",),
}


def to_board(x_mm, y_mm):
    return (ORIGIN_MM[0] + x_mm, ORIGIN_MM[1] - y_mm)


def _point(x_mm, y_mm):
    bx, by = to_board(x_mm, y_mm)
    return pcbnew.VECTOR2I(pcbnew.FromMM(bx), pcbnew.FromMM(by))


def accepted_placement():
    """The placement a search accepted, if one has been recorded.

    Absent, the seed below is the placement. Present, it replaces the seed
    for every part that is not locked - a locked part is locked in the board
    file and the search cannot have moved it, so accepting one from this file
    would be accepting a value that never came from a search.
    """
    if not os.path.isfile(PLACEMENT_PATH):
        return {}
    with open(PLACEMENT_PATH, encoding="utf-8") as handle:
        document = json.load(handle)
    return {reference: tuple(pose)
            for reference, pose in document["placement"].items()
            if reference not in LOCKED_REFERENCES}


def seed_placement():
    return dict(SEED_PLACEMENT)


#: How far apart two courtyards are pushed when they overlap, beyond the
#: overlap itself. Small, because the seed is meant to be close to legal and
#: this only takes up the slack.
LEGALISE_MARGIN_MM = 0.3
LEGALISE_PASSES = 400
#: Below this the two courtyards are touching at the margin rather than
#: overlapping, and pushing again would never end.
LEGALISE_EPSILON_MM = 1.0e-6


def _courtyard_offsets(part, rotation):
    """The courtyard as offsets from the part's own origin, y up.

    Not a half-extent: a receptacle's courtyard is not centred on its origin,
    and treating it as if it were puts parts inside it.
    """
    library_dir, name = _footprint_dir(part["footprint"])
    footprint = pcbnew.FootprintLoad(library_dir, name)
    footprint.SetOrientationDegrees(rotation)
    box = footprint.GetCourtyard(pcbnew.F_CrtYd).BBox()
    return (pcbnew.ToMM(box.GetLeft()), -pcbnew.ToMM(box.GetBottom()),
            pcbnew.ToMM(box.GetRight()), -pcbnew.ToMM(box.GetTop()))


def legalise(placed):
    """Push overlapping courtyards apart, holding the locked parts still.

    The seed placement states where each part belongs; this only resolves the
    overlaps that stating it by hand leaves behind, and it resolves them by
    moving the part that is free to move.
    """
    extents = {}
    for reference, (_, _, rotation) in placed.items():
        part = netlist.PARTS[reference]
        if not part["footprint"]:
            continue
        extents[reference] = _courtyard_offsets(part, rotation)
    poses = {reference: [x, y, rotation]
             for reference, (x, y, rotation) in placed.items()
             if reference in extents}
    order = sorted(poses)
    for _ in range(LEGALISE_PASSES):
        moved = False
        for index, first in enumerate(order):
            for second in order[index + 1:]:
                if first in LOCKED_REFERENCES and second in LOCKED_REFERENCES:
                    continue
                ax, ay, _ = poses[first]
                bx, by, _ = poses[second]
                ax0, ay0, ax1, ay1 = extents[first]
                bx0, by0, bx1, by1 = extents[second]
                overlap_x = min(ax + ax1, bx + bx1) \
                    - max(ax + ax0, bx + bx0) + LEGALISE_MARGIN_MM
                overlap_y = min(ay + ay1, by + by1) \
                    - max(ay + ay0, by + by0) + LEGALISE_MARGIN_MM
                if (overlap_x <= LEGALISE_EPSILON_MM
                        or overlap_y <= LEGALISE_EPSILON_MM):
                    continue
                moved = True
                if overlap_x < overlap_y:
                    axis, push = 0, overlap_x
                    direction = 1.0 if ax + (ax0 + ax1) / 2.0 \
                        >= bx + (bx0 + bx1) / 2.0 else -1.0
                else:
                    axis, push = 1, overlap_y
                    direction = 1.0 if ay + (ay0 + ay1) / 2.0 \
                        >= by + (by0 + by1) / 2.0 else -1.0
                free = [reference for reference in (first, second)
                        if reference not in LOCKED_REFERENCES]
                share = (push + LEGALISE_EPSILON_MM) / len(free)
                for reference in free:
                    sign = direction if reference == first else -direction
                    poses[reference][axis] += sign * share
        if not moved:
            break
    else:
        raise RuntimeError("courtyards could not be separated")
    return {reference: (round(pose[0], 4), round(pose[1], 4), pose[2])
            for reference, pose in poses.items()}


def fixed_placements():
    placed = seed_placement()
    for reference, pose in accepted_placement().items():
        if reference not in placed:
            raise KeyError("accepted placement names an unknown part: "
                           + reference)
        placed[reference] = pose
    missing = sorted(reference for reference, part in netlist.PARTS.items()
                     if part["footprint"] and reference not in placed)
    if missing:
        raise KeyError("no placement for " + ", ".join(missing))
    return legalise(placed)


def _footprint_dir(footprint):
    library, _, name = footprint.partition(":")
    for base in FOOTPRINT_SEARCH_PATHS:
        candidate = os.path.join(base, library + ".pretty")
        if os.path.isfile(os.path.join(candidate, name + ".kicad_mod")):
            return candidate, name
    raise FileNotFoundError(footprint)


_PIN_NAMES = {}


def _pin_name(lib_id, number):
    if lib_id not in _PIN_NAMES:
        library = ksym.Library(netlist.SYMBOL_LIBRARY_PATHS)
        _PIN_NAMES[lib_id] = {
            key: pins[0].name for key, pins in library.pins(lib_id).items()}
    return _PIN_NAMES[lib_id].get(number, "")


def _floating_net(board, reference, number):
    lib_id = netlist.PARTS[reference]["lib_id"]
    name = "unconnected-(%s-%s-Pad%s)" % (
        reference, _pin_name(lib_id, number).replace("/", "{slash}"), number)
    existing = board.GetNetInfo().GetNetItem(name)
    if existing is not None and existing.GetNetCode() != 0:
        return existing
    net = pcbnew.NETINFO_ITEM(board, name)
    board.Add(net)
    return net


def _load(board, reference, part, x, y, rotation, pin_net, nets):
    library_dir, name = _footprint_dir(part["footprint"])
    footprint = pcbnew.FootprintLoad(library_dir, name)
    if footprint is None:
        raise RuntimeError("could not load " + part["footprint"])
    library = part["footprint"].partition(":")[0]
    footprint.SetFPID(pcbnew.LIB_ID(library, name))
    footprint.SetPosition(_point(x, y))
    footprint.SetOrientationDegrees(rotation)
    footprint.SetReference(reference)
    footprint.SetValue(part["value"])
    footprint.Reference().SetLayer(pcbnew.F_Fab)
    footprint.Value().SetLayer(pcbnew.F_Fab)
    for key, value in (("MPN", part["mpn"]), ("LCSC", part["lcsc"]),
                       ("Manufacturer", part["manufacturer"])):
        if not value:
            continue
        footprint.SetField(key, value)
        for field in footprint.GetFields():
            if field.GetName() == key:
                field.SetLayer(pcbnew.F_Fab)
                field.SetVisible(False)
    if not part["in_bom"]:
        footprint.SetExcludedFromBOM(True)
    if reference in LOCKED_REFERENCES:
        footprint.SetLocked(True)
    for pad in footprint.Pads():
        number = pad.GetNumber()
        if not number:
            continue
        net_name = pin_net.get("%s.%s" % (reference, number))
        if net_name:
            pad.SetNet(nets[net_name])
        else:
            pad.SetNet(_floating_net(board, reference, number))
    board.Add(footprint)
    return footprint


def _nets(board):
    created = {}
    for name in sorted(netlist.NETS):
        net = pcbnew.NETINFO_ITEM(board, name)
        board.Add(net)
        created[name] = net
    return created


def _design_settings(board):
    board.SetCopperLayerCount(2)
    settings = board.GetDesignSettings()
    settings.m_TrackMinWidth = pcbnew.FromMM(0.15)
    settings.m_ViasMinSize = pcbnew.FromMM(0.45)
    settings.m_MinThroughDrill = pcbnew.FromMM(0.25)
    settings.m_CopperEdgeClearance = pcbnew.FromMM(EDGE_CLEARANCE_MM)
    settings.m_HoleClearance = pcbnew.FromMM(0.25)
    settings.m_HoleToHoleMin = pcbnew.FromMM(0.25)
    settings.m_ViasMinAnnularWidth = pcbnew.FromMM(0.1)
    settings.m_MinClearance = pcbnew.FromMM(CLEARANCE_MM)
    default_class = settings.m_NetSettings.GetDefaultNetclass()
    default_class.SetClearance(pcbnew.FromMM(CLEARANCE_MM))
    default_class.SetTrackWidth(pcbnew.FromMM(TRACK_WIDTH_MM))
    default_class.SetViaDiameter(pcbnew.FromMM(VIA_DIAMETER_MM))
    default_class.SetViaDrill(pcbnew.FromMM(VIA_DRILL_MM))


def _add_outline(board):
    corners = [(0.0, 0.0), (BOARD_W_MM, 0.0), (BOARD_W_MM, BOARD_H_MM),
               (0.0, BOARD_H_MM)]
    closed = corners + [corners[0]]
    for start, end in zip(closed, closed[1:]):
        shape = pcbnew.PCB_SHAPE(board)
        shape.SetShape(pcbnew.SHAPE_T_SEGMENT)
        shape.SetStart(_point(*start))
        shape.SetEnd(_point(*end))
        shape.SetLayer(pcbnew.Edge_Cuts)
        shape.SetWidth(pcbnew.FromMM(EDGE_WIDTH_MM))
        board.Add(shape)


def _rectangle_zone(board, corners, layers):
    zone = pcbnew.ZONE(board)
    layer_set = pcbnew.LSET()
    for layer in layers:
        layer_set.addLayer(layer)
    zone.SetLayerSet(layer_set)
    outline = zone.Outline()
    outline.NewOutline()
    for x, y in corners:
        bx, by = to_board(x, y)
        outline.Append(pcbnew.FromMM(bx), pcbnew.FromMM(by))
    return zone


def _pour(board, net, corners, layers, priority=0, remove_islands=False):
    zone = _rectangle_zone(board, corners, layers)
    zone.SetNet(net)
    zone.SetAssignedPriority(priority)
    zone.SetLocalClearance(pcbnew.FromMM(CLEARANCE_MM))
    zone.SetMinThickness(pcbnew.FromMM(0.2))
    zone.SetPadConnection(pcbnew.ZONE_CONNECTION_FULL)
    zone.SetThermalReliefGap(pcbnew.FromMM(0.3))
    zone.SetThermalReliefSpokeWidth(pcbnew.FromMM(0.4))
    if remove_islands:
        zone.SetIslandRemovalMode(pcbnew.ISLAND_REMOVAL_MODE_ALWAYS)
    board.Add(zone)
    return zone


def _box(x0, y0, x1, y1):
    return [(x0, y0), (x1, y0), (x1, y1), (x0, y1)]


#: Points a pour must reach beyond its own pads: where a generated neck
#: ends. Without these a pour could be sized around its pads and leave the
#: copper that feeds it outside.
POUR_EXTRA_POINTS = {}
for _pad_reference, _steps in ():
    pass


def _neck_endpoints():
    """Where each generated neck ends, by the net it carries."""
    endpoints = {}
    mapping = netlist.pin_to_net()
    for pad_reference, steps in GENERATED_NECKS:
        if pad_reference.startswith("__bar_"):
            name = RECEPTACLE_SUPPLY[pad_reference[len("__bar_"):]]
        else:
            name = mapping[pad_reference]
        endpoints.setdefault(name, []).append(steps[-1][:2])
    return endpoints
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

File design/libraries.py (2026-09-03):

"""Symbols and land patterns this board draws itself, from the package
drawings frozen in `evidence/`.

Every dimension below cites the document it came from. A symbol is drawn
here when the installed KiCad library has no symbol for the part, or has one
whose pin numbering or unit split does not match the package the board
actually fits; a land pattern is drawn here when the drawing states a
recommended pattern that no installed footprint reproduces.
"""
from __future__ import annotations

import os
import sys

REPO_ROOT = os.path.dirname(os.path.dirname(os.path.abspath(__file__)))
LIBRARY_NAME = "LiIonPowerBank"
SYMBOL_LIB_PATH = os.path.join(REPO_ROOT, "library",
                               LIBRARY_NAME + ".kicad_sym")
FOOTPRINT_DIR = os.path.join(REPO_ROOT, "library", LIBRARY_NAME + ".pretty")
SYM_LIB_TABLE = os.path.join(REPO_ROOT, "sym-lib-table")
FP_LIB_TABLE = os.path.join(REPO_ROOT, "fp-lib-table")

SYMBOL_LIB_VERSION = "20251024"
FOOTPRINT_VERSION = "20260206"
GENERATOR = "liion-power-bank-design-source"

# IP5306 V1.10, pin definition table: VIN, LED1, LED2, LED3, KEY, BAT, SW,
# VOUT on pins 1..8 and the power pad connected to GND. The pad is drawn as
# pin 9 because it is the device's only ground connection and a symbol that
# leaves it off cannot be checked against the land pattern.
IP5306_SYMBOL_NAME = "IP5306"
IP5306_PINS = [("1", "VIN", "power_in", "left"),
               ("6", "BAT", "power_in", "left"),
               ("7", "SW", "passive", "right"),
               ("8", "VOUT", "power_out", "right"),
               ("2", "LED1", "output", "right"),
               ("3", "LED2", "output", "right"),
               ("4", "LED3", "output", "right"),
               ("5", "KEY", "input", "left"),
               ("9", "GND", "power_in", "bottom")]
IP5306_DATASHEET = ("https://datasheet.lcsc.com/datasheet/pdf/"
                    "309666add984eaea02a8f06d99102496.pdf")

# DW01A Rev B, pin configuration table: OD, VM, OC, TD, VCC, GND on pins
# 1..6. TD is a test pin and the datasheet's own application circuit leaves
# it open, so it is drawn and declared no-connect rather than omitted.
DW01A_SYMBOL_NAME = "DW01A"
DW01A_PINS = [("5", "VCC", "power_in", "left"),
              ("2", "VM", "input", "left"),
              ("4", "TD", "input", "left"),
              ("1", "OD", "output", "right"),
              ("3", "OC", "output", "right"),
              ("6", "GND", "power_in", "bottom")]
DW01A_DATASHEET = ("https://datasheet.lcsc.com/datasheet/pdf/"
                   "0d2b2b5e8d1207bf276387cb4ff3a495.pdf")

# LM393 in one symbol rather than the installed library's three units. The
# design source places exactly one symbol per package, so a part split into
# units would leave two thirds of its pins unplaced and its supply pins on a
# unit nothing instantiates.
LM393_SYMBOL_NAME = "LM393"
LM393_PINS = [("3", "INA+", "input", "left"),
              ("2", "INA-", "input", "left"),
              ("5", "INB+", "input", "left"),
              ("6", "INB-", "input", "left"),
              ("1", "OUTA", "open_collector", "right"),
              ("7", "OUTB", "open_collector", "right"),
              ("8", "V+", "power_in", "top"),
              ("4", "V-", "power_in", "bottom")]
LM393_DATASHEET = ("https://datasheet.lcsc.com/datasheet/pdf/"
                   "0a7f69005bd54ef2bf3e8b1a5a2f8965.pdf")

# TLV431 SLVS139V, "6 Pin Configuration and Functions", DBZ (SOT-23-3)
# package: REF, CATHODE, ANODE on pins 1, 2, 3.
TLV431_SYMBOL_NAME = "TLV431A"
TLV431_PINS = [("1", "REF", "input", "left"),
               ("2", "K", "passive", "top"),
               ("3", "A", "passive", "bottom")]
TLV431_DATASHEET = ("https://datasheet.lcsc.com/datasheet/pdf/"
                    "1f0b6b30afca4cb79b547decc5f49aec.pdf")

# AO3415A Rev 3.0, SOT23 pin figure: gate, source, drain on pins 1, 2, 3.
AO3415A_SYMBOL_NAME = "AO3415A"
AO3415A_PINS = [("1", "G", "input", "left"),
                ("2", "S", "passive", "top"),
                ("3", "D", "passive", "bottom")]
AO3415A_DATASHEET = ("https://datasheet.lcsc.com/datasheet/pdf/"
                     "4fe5043a2c3149108be834737fd7b448.pdf")

# AO8810 Rev 8, TSSOP-8 top view: D1/D2 on pins 1 and 8, S1 on 2 and 3, G1
# on 4, G2 on 5, S2 on 6 and 7. Both drain pins and both pins of each source
# are drawn, so the schematic and the land pattern agree pad for pad instead
# of relying on a note that the rest are connected internally.
AO8810_SYMBOL_NAME = "AO8810"
AO8810_PINS = [("4", "G1", "input", "left"),
               ("5", "G2", "input", "left"),
               ("2", "S1", "passive", "left"),
               ("3", "S1", "passive", "left"),
               ("6", "S2", "passive", "right"),
               ("7", "S2", "passive", "right"),
               ("1", "D", "passive", "right"),
               ("8", "D", "passive", "right")]
AO8810_DATASHEET = ("https://datasheet.lcsc.com/datasheet/pdf/"
                    "26d8ed0c631e45aaacbd4f8082ccbf0c.pdf")

# A single-throw push button whose land pattern carries four pads: the two
# pads of each terminal are separate pins so every pad on the board belongs
# to a pin the schematic names.
SWITCH_SYMBOL_NAME = "SW_Push_4P"
SWITCH_PINS = [("1", "A", "passive", "left"),
               ("2", "A", "passive", "left"),
               ("3", "B", "passive", "right"),
               ("4", "B", "passive", "right")]
SWITCH_DATASHEET = ("https://datasheet.lcsc.com/datasheet/pdf/"
                    "56c8799ae5193945a16a1ffbe378246a.pdf")

TVS_SYMBOL_NAME = "TPD1E10B06"
TVS_DATASHEET = "https://www.ti.com/lit/ds/symlink/tpd1e10b06.pdf"

# TI DPY0002A, drawing 4224561/C (SLLSEB1G): land pattern 2x (0.3) wide by
# 2x (0.5) tall on (0.7) centres; package outline 1.1/0.9 by 0.7/0.5.
X1SON_FOOTPRINT_NAME = "TI_X1SON-2_1.0x0.6mm_P0.65mm"
X1SON_PAD_SIZE_MM = (0.30, 0.50)
X1SON_PAD_PITCH_MM = 0.70
X1SON_BODY_MM = (1.10, 0.70)
X1SON_COURTYARD_MARGIN_MM = 0.15

# IP5306 V1.10 package information: D 4.70/4.90/5.10 body length, E1
# 3.70/3.90/4.10 body width, E 5.80/6.00/6.20 lead span, e 1.27 BSC, b
# 0.39-0.48 lead width, L 0.50/0.60/0.80 foot length, D1 = E2 = 2.09
# exposed pad. The lead pads are the JEDEC MS-012 pattern for that lead span
# and the exposed pad is the drawing's own 2.09 square, which is why this is
# drawn rather than taken from the installed library: no installed SOIC-8
# with an exposed pad carries a 2.09 square one.
ESOP8_FOOTPRINT_NAME = "ESOP-8_3.9x4.9mm_P1.27mm_EP2.09x2.09mm"
ESOP8_PITCH_MM = 1.27
ESOP8_PAD_SIZE_MM = (1.95, 0.60)
ESOP8_PAD_CENTRE_X_MM = 2.475
#: The exposed pad takes less paste than copper, because a single aperture
#: over its whole area floats the package.
ESOP8_PASTE_PAD_MM = 1.85
ESOP8_EXPOSED_PAD_MM = 2.09
ESOP8_BODY_MM = (4.90, 3.90)
ESOP8_COURTYARD_MARGIN_MM = 0.25
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

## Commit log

2026-08-30 Seed benchmark board 07/32 from its supplied brief
    PCBA_LiIon_PowerBank is one of thirty-two boards in the PCBA_AutoDesignAndTest
    benchmark. This commit establishes the repository and nothing else:
    the board is not designed, and its absence is the intended state.
    BRIEF.md is the supplied brief, preserved byte for byte and
    authoritative. board/requirements.json splits it into fixed_requirements
    -- each carrying the verbatim brief text that substantiates it, bound to
    the SHA-256 of the brief's bytes -- and open_decisions, which are the
    design agent's to make and to record as choices. Promoting a decision
    into a requirement is the failure the split exists to prevent.
    docs/architecture.md is a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
2026-08-30 Stop the scaffold claiming a check it does not perform
    An external review of the pushed benchmark found this repository asserting
    three things about itself that were not true as shipped.
    board/manifest.template.json said running the validator against it "will
    fail on the missing source". It does not: `run.py validate
    board/manifest.template.json` exits 0 and prints ACCEPTED, with all 36 gates
    NOT_APPLICABLE and no gate reading sources.pcb, so the absent board file is
    never noticed. The template now says exactly that, under verdict_warning,
    and docs/status.md and CLAUDE.md carry the same warning where a reader and
    an agent will actually meet it. The toolkit is behaving as designed - a gate
    w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
2026-08-30 Remove the claim-audit skill, and the instructions that called it
    Requested. .claude/skills/claim-audit/ is deleted, and with it every
    reference: CLAUDE.md's publishing discipline no longer names it, and the
    README layout table no longer advertises it.
    accountability-review kept calling it at step 3, which would have left the
    surviving skill invoking one that is not in the clone - the same
    dangling-instruction defect that put these skills in the repository in the
    first place. That step now states the claim-binding work directly: scan the
    drafts for claim-bearing words, and bind each to an artifact recomputed on
    the spot rather than to the process that produced it. The discipline is
    unchange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
2026-08-30 Finish removing claim-audit: the last prose reference to it
    accountability-review still explained itself with "that is why the claim
    audit runs first". Nothing runs first any more - the claim binding is step 3
    of this skill, and it runs before the review package is assembled, not
    before the review. The sentence now says that.
    Removing a skill is not done when its file is gone. It is done when nothing
    left in the repository tells a reader to go and find it.
2026-08-30 Review against this repository's own invariants, not another board's
    /accountability-review assembled its review package with a hardcoded list
    of "standing invariants", and that list belonged to a different project and
    an abandoned workflow: "never modify the authoritative Board A PCB" names a
    board that does not exist here, and "never touch main" and "no PRs"
    describe a process the opposite of this one -- every repository in this
    benchmark is developed on main and pushed directly.
    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
2026-08-30 Delete generated prose; keep the seed brief and machine-consumed config
    The seed pack already contained the human-authored specification for this
    board. Everything this repository added on top was a reinterpretation of it:
    a README and CLAUDE.md narrating the brief, an architecture worksheet of
    English questions, status and sources documents, a prose requirements
    document, and requirements.json - which restated the brief as English
    requirement strings and copied 20-odd verbatim quotations back out of a file
    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
2026-09-03 Design the LiIon power bank: schematic, layout, simulation and fabrication outputs
    [bom.csv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]
2026-09-03 Record what this board needed from the toolkit and did not have
2026-09-03 Rebind the release to the phase 0 toolkit
    The toolkit now validates every manifest against its published schema
    and refuses vocabulary it does not implement, so the board-local gate
    list moves under the x_ extension prefix; gate-class selection
    (--only=design) supersedes it. Regenerated and revalidated against
    toolkit f4d3904: 22 gates pass, 14 report NOT_APPLICABLE, and
    the fabrication record now carries the source-closure member map, so
    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
    [liion_power_bank-B_Cu.gbr, liion_power_bank-B_Mask.gbr, liion_power_bank-B_Silkscreen.gbr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]
2026-09-03 Retire the hand-written routing acceptance list
    The toolkit's design gate class replaces it: candidate acceptance now
    selects --only=design, expanded by the toolkit, so the set cannot rot
    as gates are added. The list leaves the manifest and the generator that writes it, and the
    release is regenerated under toolkit b441685, which also closes the
    review findings on the phase 0 seams: 22 gates pass, 14 report
    NOT_APPLICABLE.
    [liion_power_bank-B_Cu.gbr, liion_power_bank-B_Mask.gbr, liion_power_bank-B_Silkscreen.gbr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]
2026-09-03 Close the adversarial findings that reached this board
    The unread keys the manifest carried are gone: tolerance_seconds is
    deleted, contact_semantics becomes the note annotation it always was,
    and the schema now refuses both by name. The routing acceptance
    selection regains ROUTE.PROVENANCE - the loop writes the record before
    judging, so record-board agreement is judged per candidate as it was
    under the hand-written list. Regenerated and revalidated under
    toolkit a0f53eb: 22 gates pass, 14 report NOT_APPLICABLE.
    [liion_power_bank-B_Cu.gbr, liion_power_bank-B_Mask.gbr, liion_power_bank-B_Silkscreen.gbr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]
2026-09-03 Rebind the release to toolkit 0c051f2
    The toolkit keeps its CLI alive with no display and closes the third
    review round's findings; nothing in this board's own sources moved.
    22 gates pass, 14 report NOT_APPLICABLE.
    [liion_power_bank-B_Cu.gbr, liion_power_bank-B_Mask.gbr, liion_power_bank-B_Silkscreen.gbr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]
2026-09-03 Rebind the release to toolkit 7f51066
    The panel-fix round widened the source closure to every staged design
    input and hardened the verdict binding, so the fabrication outputs and
    the recorded verdict are regenerated under the new toolkit. The
    transient .pcbqa-hold-* lock file is ignored.
    [liion_power_bank-B_Cu.gbr, liion_power_bank-B_Mask.gbr, liion_power_bank-B_Silkscreen.gbr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]
2026-09-04 Delete the routing loop, declare the search, rebind to toolkit bd0ad78
    The 1329-line private loop - the largest in the bench - moves to the
    toolkit. The declaration reserves the pour and protection nets and
    OFFERS the front-pour nets (in scope even when closed, so the search
    repairs a pour its own copper cut), which is this board's pour-repair
    rule stated as data. same_net_pad_clearance_mm is deliberately the
    via-to-mask-opening target, annotated in the manifest; the mask-opening
    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
    [liion_power_bank-B_Cu.gbr, liion_power_bank-B_Mask.gbr, liion_power_bank-B_Silkscreen.gbr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]
2026-09-04 Drop the attempt budget to the distinct matrix, and refresh the binding
    The toolkit's review round closed the identical-attempts channel: the
    router is invoked deterministically per row, so attempts above the
    distinct orderings x clearances matrix are refused rather than cycled.
    This board declared 9 attempts over 3 distinct rows - the old private
    loop's repeat-3x budget - which now refuses at `route --check`. The
    declaration drops to its 3 distinct rows; nothing about the committed
    copper changes.
    The rebuild refreshes fabrication.json's toolkit identity and closure
    under the reviewed toolkit; the deterministic exports are byte-stable.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
    [manifest.py]
2026-09-04 Accept through the design gate class; courtyards; no raw endpoints
    The re-review held the plan to its words: "routing accepts nothing
    release will reject" means the acceptance names the design gate
    class, not a counter subset - so it now does, beside the counters.
    placement.courtyard is declared for both faces (edge clearance is
    not: this board places connectors or mounting holes at its outline
    by design, and reports that reason instead of promising a margin).
    The remaining raw GetStart()/GetEnd() reads go through
    pcbqa.board.endpoints - Phase 1.1's exit criterion, now literal.
    design/route.py is deleted per the plan; `run.py route` is the
    entry. Fabrication binding refreshed under the revie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
    [layout.py, manifest.py]
2026-09-04 Write the placement board through the project-preserving save
    The toolkit review's Phase 1.6 sweep found this board's unused
    placement-writer helper still calling pcbnew.SaveBoard directly -
    which rewrites, or invents, sibling project documents beside whatever
    path it is given. `write_placement_board` now goes through
    `pcbqa.board.save` like every other board write, and a test pins that
    no design module calls SaveBoard directly again. Revalidated under
    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
2026-09-05 Refresh the fabrication binding under the reviewed toolkit
    The toolkit's fourth review round pinned the routing judgment to its
    recorded policy at the read site, fixed the router-summary shape the
    reconciliation reads, and extended post-adoption enforcement to the
    manifest digest and recorded plan; nothing in this board's own sources
    changed. Rebuilt and revalidated so the committed verdict and closure
    name the reviewed toolkit state.
2026-09-05 Refresh the fabrication binding under the reviewed toolkit
    The toolkit's fifth review round closed its last blocker: with a
    recorded binding declared, every acceptance gate now reads the
    verified staged design instead of live pathnames. Nothing in this
    board's own sources changed. Rebuilt and revalidated so the committed
    verdict and closure name the reviewed toolkit state.
2026-09-05 Refresh the fabrication binding under the reviewed toolkit
    The toolkit's sixth review round bound every auxiliary file the
    routing acceptance gates consume - stackup supplements, contract
    documentation, simulation records - into the routing record, enforced
    at adoption, check, provenance and replay; nothing in this board's
    own sources changed. Rebuilt and revalidated so the committed verdict
    and closure name the reviewed toolkit state.
2026-09-05 Move the register to the toolkit; scenario assertions name what they judge
    The register and claim documents build through pcbqa.evidence's
    validating constructors, and the checker, anchor parser and serialiser
    this board copied from board 03 are deleted - REQ.REGISTER,
    REQ.CLAIM_JOIN and PROV.DERIVED_DOCUMENTS enforce all of it at every
    validate and release, over nine declared derived documents (register,
    claims, and all seven simulation scenarios).
    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
2026-09-05 Refresh the fabrication binding under the committed Phase 2 toolkit
    The toolkit's evidence-governance commit is a source-closure member,
    so the committed artifacts and verdict re-bind to it. Nothing in this
    board's own sources changed in this commit.
2026-09-05 Move the governance declarations into the manifest generator
    The board's own committed-manifest-is-generated test caught what the
    finishing pipeline had swallowed: the Phase 2 manifest blocks were
    scripted onto board/manifest.json while design/manifest.py still
    generated the old document. The blocks now live in design/governance
    as data the generator merges, the evidence index gains its new frozen
    entry through design/evidence.py rather than by hand, the committed
    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
2026-09-05 Adopt the round-2 review corrections: expiring dependencies, honest decline, shared registry
    Open external dependencies gain review dates; the device_parameters
    decline reason now states the true position (the assumed figures
    enter as bounds with stated assumptions, never as exact knowledge);
    and the simulation tests assemble their registry through
    pcbqa.sim.assemble.
    [governance.py]
2026-09-05 Adopt the round-3 corrections: the claim document joins the closure
    The claim document the verdict rests on joins the source closure, so
    a release tag carries it and its movement is a named staleness. The
    claims generator declaration is now mandatory toolkit-side
    (CLAIM.MATRIX refuses an unlisted document), which this board already
    satisfied.
    [governance.py]
2026-09-05 Refresh the fabrication binding: round-3 verdict rendering
    The toolkit's open-item rendering commit is a closure member; this
    board's committed verdict re-binds to it. No board sources changed.
2026-09-05 Refresh the fabrication binding: fourth-round evidence fixes
    The toolkit now lists register methods still required that no
    dependency owns as open items in the policy state - a passing claim
    establishes the number, never the separately declared method - and the
    refreshed validation record carries whatever this board honestly owes.
2026-09-05 Refresh the fabrication binding: fifth-round toolkit
    Domain enforcement now owns timing's evidence gates, refuses vacuous
    simulation declarations, and judges device-parameter validity from the
    operating point; nothing on this board changes beyond the closure.
2026-09-05 Refresh the fabrication binding: sixth-round toolkit
    PROV.DEVICE_PARAMETERS now judges applicability from the citation
    rather than from the presence of a validity range - a record with no
    stated range has no supported range. Nothing on this board changes
    beyond the closure; its citations already state their operating points.
2026-09-05 Re-freeze against the advanced fabricator catalogue
    Phase 3.1 published seven more capabilities from the SAME frozen
    evidence - hole plating thickness, the PTH annular ring, and the
    soldermask process set - so the approved catalogue's normalized digest
    moved from 953f02ea to e504b0de. Every physical input this board froze
    records the catalogue state it was resolved from, so those records were
    re-frozen against the current one.
    Nothing this board selects changed: the process selection came back
    byte-identical apart from the digest, and no physical value moved. The
    new capabilities describe plating and soldermask, which this board's
    selection does not turn on.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
2026-09-05 Decide, on the record, about the five domains Phase 3 added
    Phase 3 implements thermal, current capacity, power integrity,
    differential pair and reference continuity as evidence domains, so
    saying nothing about them is no longer a neutral act: silence lands the
    policy state on requires-additional-evidence.
    This board declines all five, each with a reason true of THIS board -
    what it does instead, or why the domain does not describe it. It cannot
    honestly declare them: declaring one means authoring a capacity basis, a
    set of thermal-resistance records or a rail mesh, and inventing any of
    that is precisely the fabrication this toolkit exists to prevent. Where
    the board already answers the que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
    [governance.py]
2026-09-05 Refresh the fabrication binding against the reviewed Phase 3 toolkit
    The toolkit is a source-closure member, so four rounds of adversarial
    review over Phase 3 mean the committed reports and the validation record
    are re-made against the code that now exists. Nothing about this board
    changed.
2026-09-06 Rebuild the artifacts against the fifth-review toolkit
    No verdict moves and no gate changes status: the round closed defects in
    the current, PDN, coverage and arc paths, and what this board exercises
    of them it already exercised correctly. The artifacts are refreshed so
    the recorded run names the toolkit commit that produced it rather than
    one four fixes behind.
2026-09-06 Correct two omissions the layout overtook, and rebind to toolkit c17ebb5
    The toolkit moved, so the artifacts were regenerated: the source closure
    goes d9f042c5 -> c2480a20 and nothing else about the design changed. The
    gerbers, BOM, CPL and archive come back byte-identical, and the verdict is
    what it was - ACCEPTED, 30 PASS / 27 NOT_APPLICABLE / 0 FAIL,
    fabrication-ready, 49/49 board tests.
    Two stated omissions were false. Both excused themselves from board copper
    because it "has not been laid out yet", and that stopped being true when the
    board routed. The omission itself stands - the copper is still absent from
    the subtraction - so what changed is the reason and not the verdict: it is
    abs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
    [rules.py]
2026-09-06 Restore the reverted process citation: both via gates run and pass
    TOOLKIT_REQUEST_2.md 19 recorded this declaration for restoration
    "unchanged once request 19 is fixed", and it is fixed: the toolkit keys
    native mask openings by pad KIID, so the USB-C shells' four SH lands
    are four objects again and the 59 spurious "nearest mask opening is a
    different object" findings are gone. The catalog pin, the
    soldermask_opening_to_trace_mm citation and the two gates return to the
    manifest, with 19a's reasoning recorded in the interpretation: the
    neighbouring filled_via_to_opening_mm fact is NOT the one to cite,
    because its own conditions scope it to soldermask-filled vias no wider
    than 0.5 mm and this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
2026-09-06 Rebuild the artifacts against the review-response toolkit
    No verdict moves and no gate changes status. The round closed the
    island-barrel channel in the PDN mesh, scoped the thermal copper
    ceiling to a named pad, and corrected two verdict texts; what this
    board exercises of them it already exercised correctly, and the refresh
    binds the record to the toolkit commit that produced it.
2026-09-06 Rebuild the artifacts against the second-pass toolkit
    No verdict moves and no gate changes status. The pass closed the
    untested through-hole half of the island-barrel filter and composed
    every standing THERMAL.DERATING problem into its verdict; what this
    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
2026-09-06 Rebuild the artifacts against the fragility-knob toolkit
    No verdict moves and no gate changes status. The toolkit pins
    KICAD_PLANE_FRAGILITY_COST=0 for every FUTURE owned search - KiCad's
    zone filler is a thread race the field inherited, core pinning
    measurably does not close it, and disabling the field is deterministic
    by construction. This board's adopted route and record are untouched:
    the knob binds searches, not validations, and a replay of the old
    record now refuses the environment check as it should. The refresh
    binds the artifacts to the toolkit commit that produced them.
2026-09-07 Rebuild the artifacts against the fill-oracle-account toolkit
    No verdict moves and no gate changes status. The wrapper now refuses a
    router summary that cannot account for which pour geometry its
    fragility field used; this board's adopted route and record are
    untouched, and the refresh binds the artifacts to the toolkit commit
    that produced them.
2026-09-07 Rebuild the artifacts against the upstream-merged toolkit
    No verdict moves and no gate changes status. The pinned router advanced
    through 254 upstream commits (grid_router v0.22.0, the #831 fill-oracle
    account the wrapper now reads, the --clearance semantics split); this
    board's adopted route and record are untouched, future searches inherit
    the new semantics, and the refresh binds the artifacts to the toolkit
    commit that produced them.
2026-09-11 Retire this board's toolkit request files
    Removed at the operator's direction. The program rule is that a request
    is closed by deletion rather than by a status note, and the toolkit
    work these asked for has been landing across phases 0 to 4; the files
    themselves stay readable in this repository's history, which is where a
    closed request belongs.
2026-09-11 Generate the via-mask citation the manifest already ships
    board/manifest.json carried a catalog pin, a via_mask.process citation
    and two mandatory gates that design/manifest.py has never produced. The
    committed manifest was edited by hand and the generator was left behind,
    so this repository's own test that the two agree has been failing:
    FAIL: test_the_committed_manifest_is_the_generated_one
    Nothing in the toolkit catches it, because board/manifest.json is not a
    derived document - PROV.DERIVED_DOCUMENTS checks the nine that are. The
    generator's own docstring names the failure mode it fell into: "a
    manifest typed by hand is a second copy of all of it that can drift
    from the first. So i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
    [manifest.py]
2026-09-11 Decide the two domains Phase 4 added, and rebuild on KiCad 10.0.6
    The toolkit's own last commit states the consequence: "every board must
    now declare or decline these two domains, exactly as Phase 3's physics
    domains required. Until each does, its policy state is
    requires-additional-evidence - correctly, because silence is not a
    decision." This board was silent, and its policy state said so. The
    gates were all still ACCEPTED; a release-check would have refused.
    Both are declined, and the reasons say what would have to exist first.
    lifecycle wants a status per fitted part with its basis and evidence
    bytes behind a digest. This board holds stock and price in
    components/jlcpcb.json from 2026-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
    [liion_power_bank-B_Cu.gbr, liion_power_bank-B_Mask.gbr, liion_power_bank-B_Silkscreen.gbr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]
2026-09-12 The Power netclass named eight nets and judged none of them
    Phase 5.5 added DRC.NETCLASS_COHERENCE - "a rule that binds nothing
    judges nothing" - and it fails this board on the first run.
    The project declared the wide class's membership in a `nets` list
    inside the class entry, the KiCad 6 shape. `kicad-cli pcb drc` does not
    read it. So BAT, CELLN, GND, SW, VBUS, VIN, VOUT and VOUT_SW all
    resolved to Default, and the Power class - clearance, track width, via
    diameter, via drill - reached nothing on the board.
    Measured on this board's own copper rather than argued, KiCad 10.0.6,
    the same board file each time and only the membership channel changed:
    Power clearance 0.9 mm, membership in th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
    [build.py, manifest.py]
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
